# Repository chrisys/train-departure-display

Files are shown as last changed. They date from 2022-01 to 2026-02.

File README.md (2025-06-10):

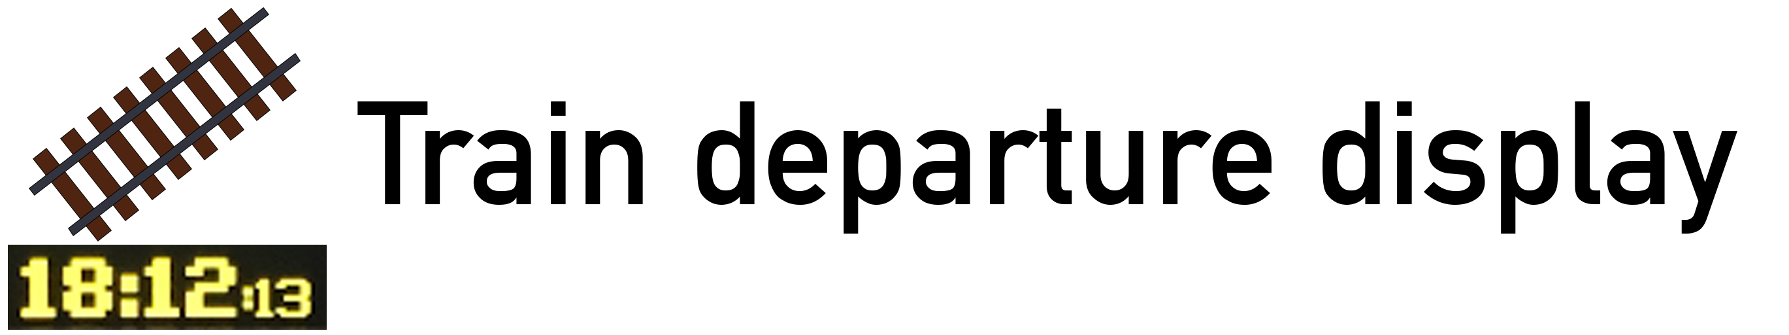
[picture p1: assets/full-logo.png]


**A replica, near real-time, miniature UK railway station train departure sign based upon a Raspberry Pi Zero and 256x64 SPI OLED display(s). Uses the publicly available [OpenLDBWS API by National Rail Enquiries](https://www.nationalrail.co.uk/).**

## Highlights

- **See local departures**: Display the depatures from your local station at home for up to date train information.
- **3D-printable cases**: Print your own miniature case to keep everything tidy - both desktop and 'hanging' style available.
- **Dual display support**: Run two displays each showing departures from different platforms from a single Raspberry Pi.

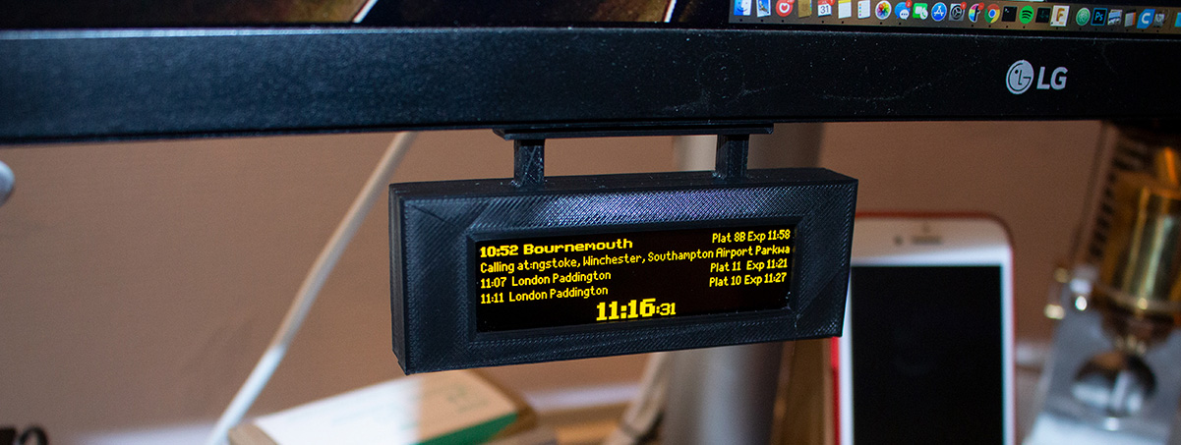
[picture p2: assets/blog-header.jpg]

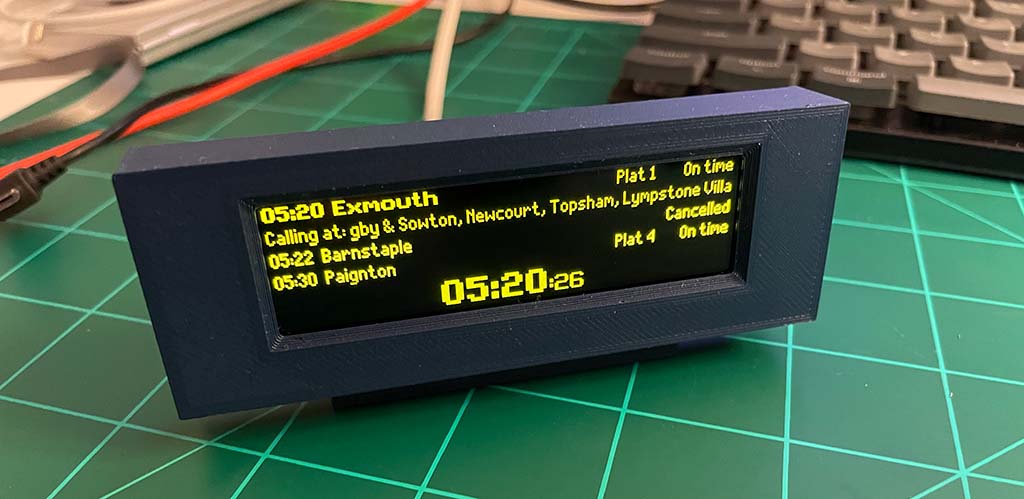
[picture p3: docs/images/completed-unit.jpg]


## How to build

**Check out [the documentation](/docs/01-getting-started.md) for full hardware/software requirements and complete build guide.**

- [Getting Started](/docs/01-getting-started.md)
- [Connecting the display to the Pi](/docs/02-connecting-the-display-to-the-pi.md)
- [Assembling the Case](/docs/03-assembling-the-case.md)
- [Configuration](/docs/04-configuration.md)

## Credits

A big thanks to [Chris Hutchinson](https://github.com/chrishutchinson/) who originally started this project and inspired me to develop it further. [Blake](https://github.com/ghostseven) made some further improvements and this project was forked from [there](https://github.com/ghostseven/UK-Train-Departure-Display).

The fonts used were painstakingly put together by `DanielHartUK` and can be found on GitHub at https://github.com/DanielHartUK/Dot-Matrix-Typeface - A huge thanks for making that resource available!

Thanks to [@jajasilver](https://github.com/jajsilver/UK-Train-Departure-Display-NRE) and [@MatthewAscough](https://github.com/MatthewAscough/UK-Train-Departure-Display-NRE) for forming the basis of the OpenLDBWS implementation.

Thanks to [@cr3ative](https://github.com/cr3ative) and [@CalamityJames](https://github.com/CalamityJames) for the huge performance improvements and clean up in v0.5.0.

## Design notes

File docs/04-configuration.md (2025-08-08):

# Configuration

Sign up for the [National Rail Enquiries OpenLDBWS API](http://realtime.nationalrail.co.uk/OpenLDBWSRegistration), which will generate an token for you to use as the API key.

Only the API key is required to make the project run, everything else is optional but of course it may make sense for you to at least choose your preferred your station.

These environment variables are specified using the [balenaCloud dashboard](https://www.balena.io/docs/learn/manage/serv-vars/), allowing you to set up mutiple signs in one fleet for different stations.

| Key | Example Value
|---|---
|`apiKey` **(REQUIRED)** | `xxxxxxxx-xxxx-xxxx-xxxx-xxxxxxxxxxxx` (OpenLDBWS API key)
|`TZ`  | `Europe/London`, will default to UTC if not set ([timezones](https://en.wikipedia.org/wiki/List_of_tz_database_time_zones))
|`departureStation`  | `PAD` ([station code](https://www.nationalrail.co.uk/stations_destinations/48541.aspx))
|`destinationStation`  | `HWV` ([station code](https://www.nationalrail.co.uk/stations_destinations/48541.aspx)) [optional] Filters trains shown to only those that call at this station
|`timeOffset`  | `5` [optional] (Time offset, in minutes, for the departure board. Can be used to see into the future (positive value) or past (negative value). Set 5 if you live 5 min from the station and want to hide departures that are too soon to catch)
|`refreshTime` | `120` (seconds between data refresh)
|`screenRotation` | `2` (rotates the output of the OLED, 0 for when using the desk stand, 2 for the monitor mount ([docs](https://luma-oled.readthedocs.io/en/latest/api-documentation.html#luma.oled.device.ssd1322)))
|`operatingHours` | `8-22` (hours during which the data will refresh at the interval above - leave blank to run all day)
|`screenBlankHours` | `1-6` (hours during which the screen will be blank and data will not refresh - leave blank to never blank)
| `outOfHoursName` | `London Paddington` (name shown when current time is outside the `operatingHours`)
| `dualScreen` | `True` (if you are using two displays)
| `screen1Platform` | `1` (sets the platform you want to have displayed on the first or single-screen display)
| `screen2Platform` | `2` (sets the platform you want to have displayed on the second display)
| `individualStationDepartureTime` | `False` (Displays the estimated or scheduled time of the service at each leg of a journey)
| `fpsTime` | `4` (adjusts how often the effective FPS is displayed)
| `headless` | `True` (outputs to noop serial device rather than serial port; useful for running on a development machine)
| `showDepartureNumbers` | `True` (adds 1st / 2nd / 3rd as per UK train departures)
| `firstDepartureBold` | `False` (makes the first departure use either the bold or normal font)
| `targetFPS` | `20` (Frame rate regulator FPS target; 0 disables the regulator, which will increase FPS on constrained CPU, but will run the CPU hot at 100%.)
| `debug` | `False` (Display debugging information; `True` shows the debug info permanently, any integer `>1` will show instead of the splash screen for that number of seconds)

If using two screens the following line needs to be added into /boot/config.txt which is achieved by using the 'Define DT overlays' option within the Device configuration screen on balenaCloud: `spi1-3cs`



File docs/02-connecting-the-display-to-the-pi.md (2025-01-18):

# Connecting the display to the Pi

The next thing we need to tackle once you have obtained what you need from the [hardware required](01-getting-started.md#hardware-required) list is connecting the display to the Raspberry Pi and assembling the case.

## Configuring the display

Some displays have a solder-blob or zero-ohm resistor jumper on the back of the board that you may need to move in order to enable the display for SPI communication. In the case of my display it meant moving `R6` to `R5` to enable 4SPI as dictated by a small data table printed on the back of the display board. This may not be necessary if you get a different display, but it has been for every display I have used so far.

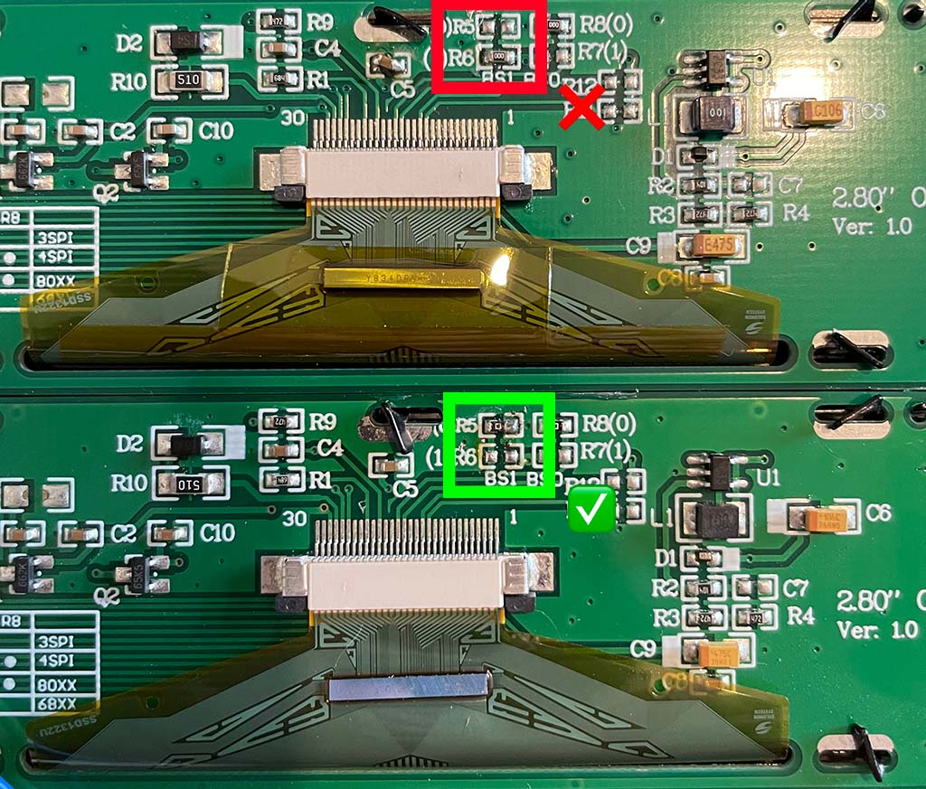
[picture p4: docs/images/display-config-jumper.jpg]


**Note:** this resistor is of zero value, so if it's easier you can remove it from one position and just bridge the pads with solder instead. A user also reported it's possible to do this with conductive paint in the case you are building the project without soldering.

## Required connections

The connections for one of these displays to the Raspberry Pi GPIO header are as follows, but **it would be a good idea to check the connections with the datasheet of your particular display before powering on** as there's no guarantee yours will match the pinout of mine.

### Display 1

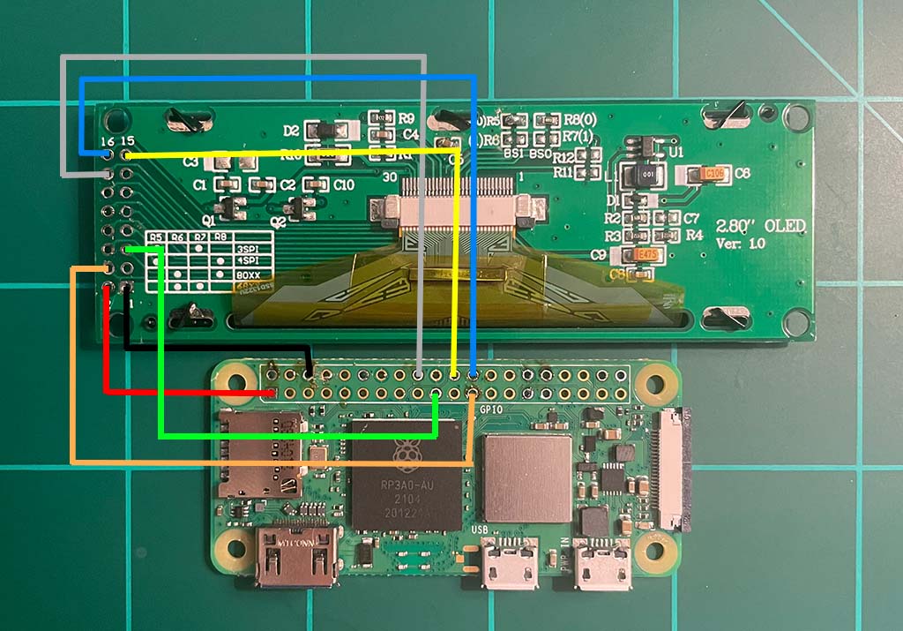
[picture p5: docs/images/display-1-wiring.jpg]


| Display | Connection | Raspberry Pi
|---|---|---
| 1 | Ground | 6 (Ground) |
| 2 | V+ (3.3V) | 1 (3v3 Power) |
| 4 | `D0/SCLK` | 23 (`BCM11 SCLK`) |
| 5 | `D1/SDIN` | 19 (`BCM10 MOSI`) |
| 14 | `DC` (data/command select) | 18 (`BCM24`) |
| 15 | `RST` (reset) | 22 (`BCM25`) |
| 16 | `CS` (chip select) | 24 (`BCM8 CE0`)

### Display 2 (optional)
**Note:** when using 2 displays there's [additional configuration required](./04-configuration.md).
| Display 2 | Connection | Raspberry Pi
|---|---|---
| 1 | Ground | 25 (Ground) |
| 2 | V+ (3.3V) | 17 (3v3 Power) |
| 4 | `D0/SCLK` | 40 (`BCM21 SCLK`) |
| 5 | `D1/SDIN` | 38 (`BCM20 MOSI`) |
| 14 | `DC` (data/command select) | 29 (`BCM5`) |
| 15 | `RST` (reset) | 31 (`BCM6`) |
| 16 | `CS` (chip select) | 12 (`BCM18 CE0`)

## Making the connections

The idea when making the connections between the display and the Raspberry Pi is to be as neat as possible and keep the wires only as long as necessary. Space within the case is limited and any extra wiring may make it difficult to fit all of the components in.

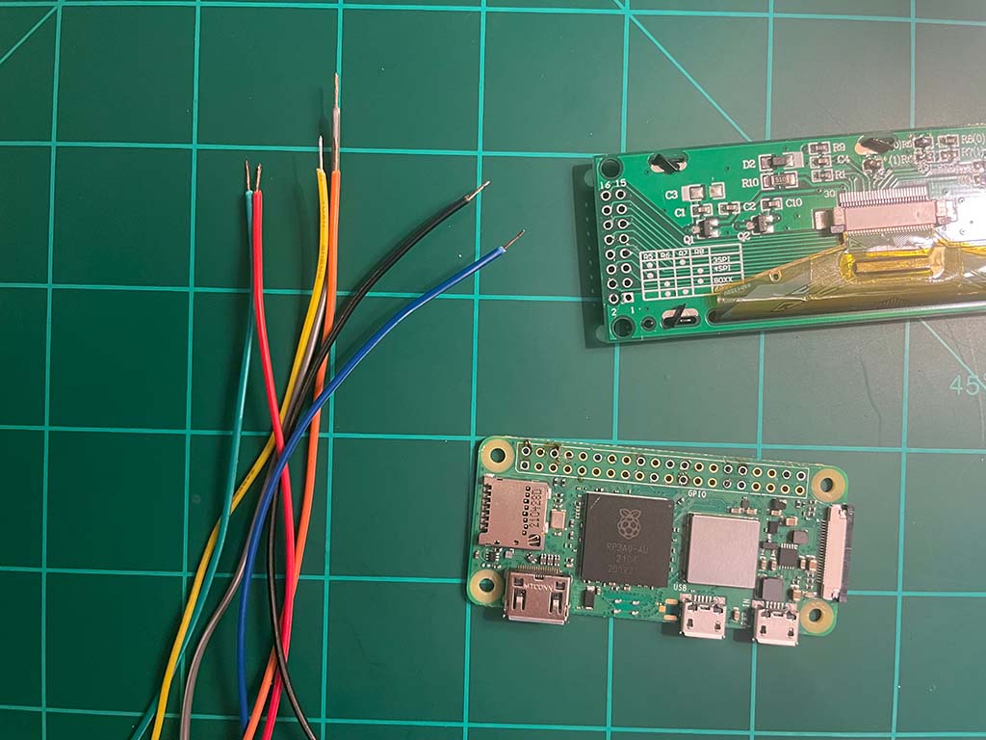
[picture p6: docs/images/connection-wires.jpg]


Strip the ends of each wire and make all the connections to the display first. I used the same colour wires as in my wiring diagram to save confusion.

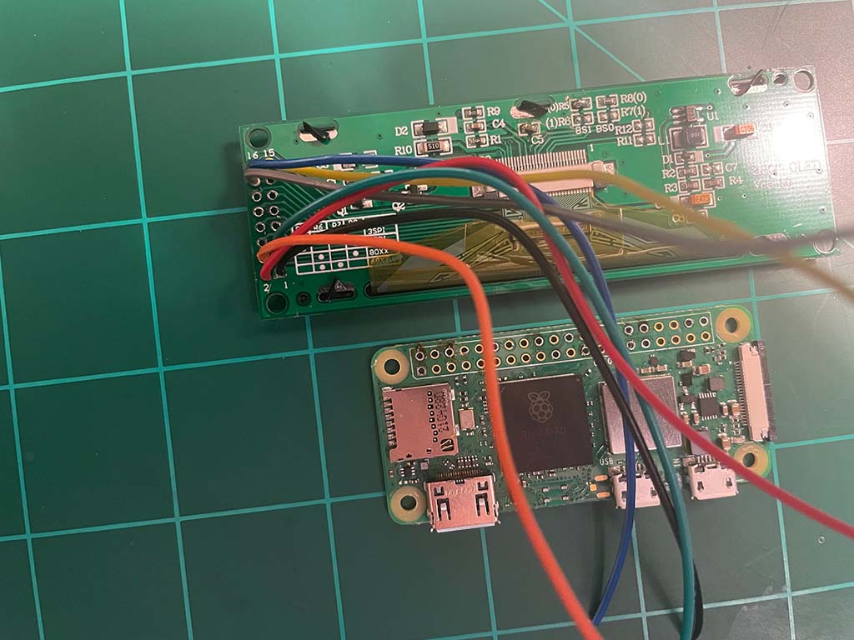
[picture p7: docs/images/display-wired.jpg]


Next, connect each of the wires to the appropriate place on the Pi, working from left to right. Again, make sure wires are only as long as necessary to make the connection.

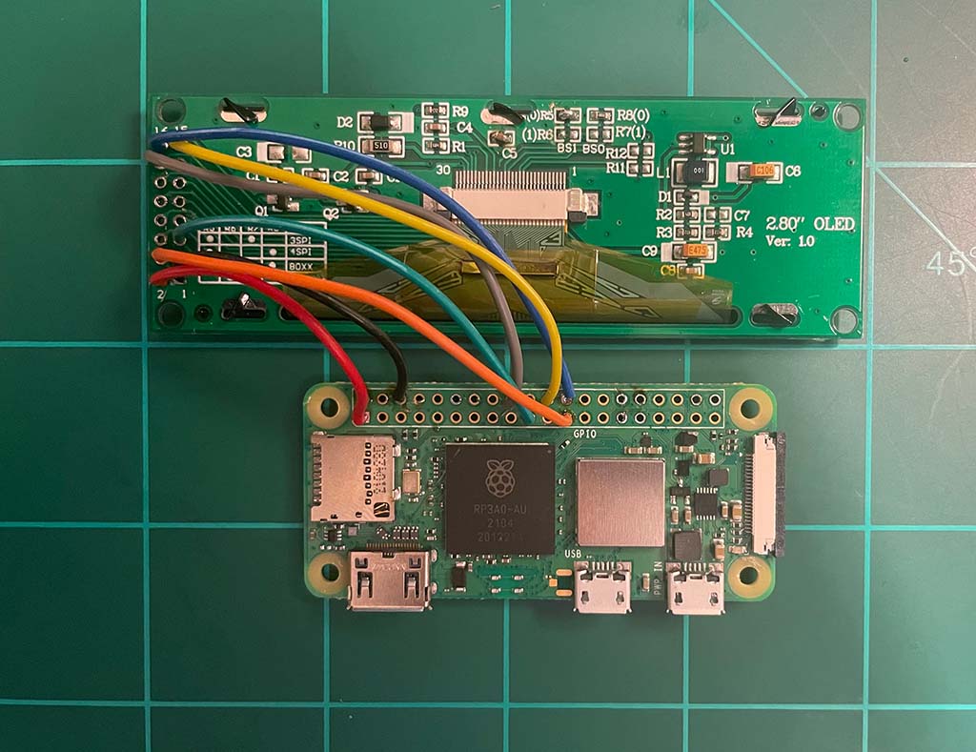
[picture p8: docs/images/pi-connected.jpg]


## Testing

At this point you can install the SD card into the Pi and power it up. If you've connected everything correctly you should see the initial welcome screen of the display, but nothing more since we haven't configured it yet (that comes later!).

## Troubleshooting

If at this point you're not seeing the Train Departure Display welcome screen, don't worry, just double check all of your connections one by one, and review the note at the beginning of this guide about the resistor/solder-blob configuration. It can be different per-display, and we need to make sure the display is set to 4-wire SPI mode before it will work.

**Next up: [Assembling the case](./03-assembling-the-case.md)**

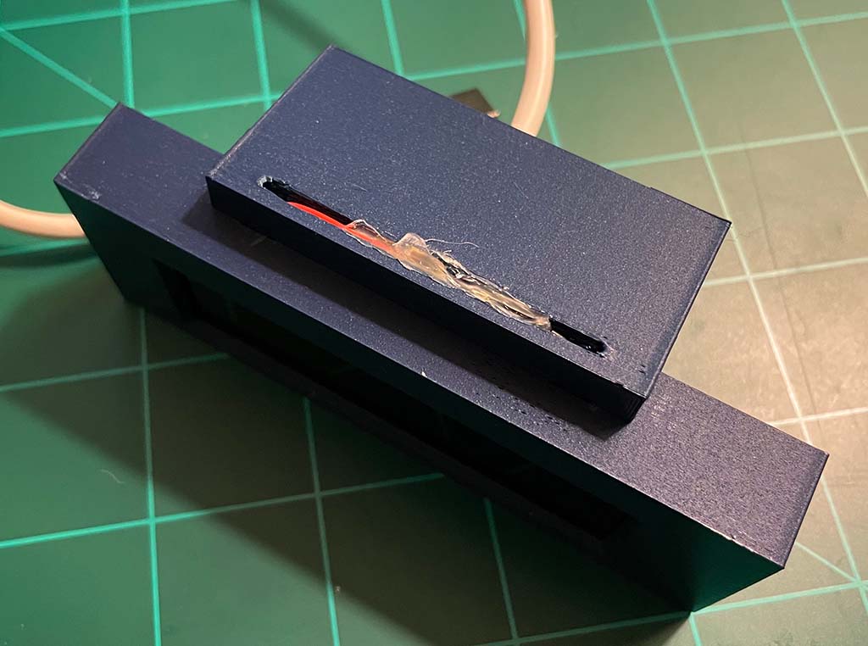
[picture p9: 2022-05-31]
docs/images/hot-glue.jpg

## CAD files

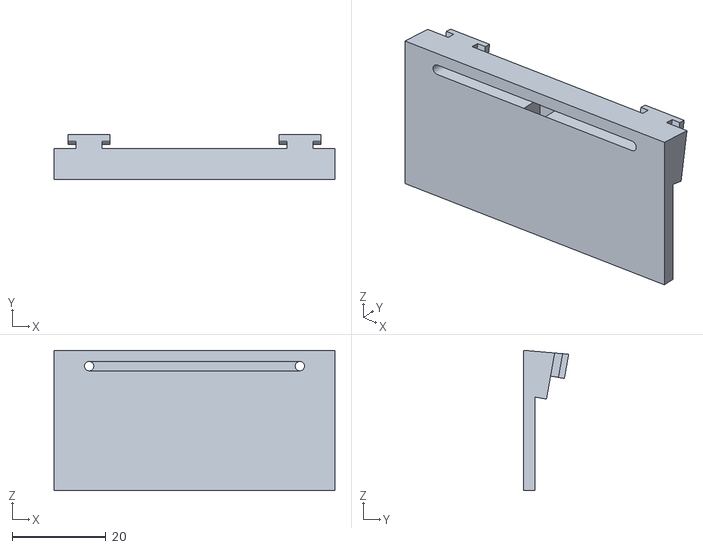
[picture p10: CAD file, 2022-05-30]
case/desk-mount.stl
60.0 x 9.70 x 30.0

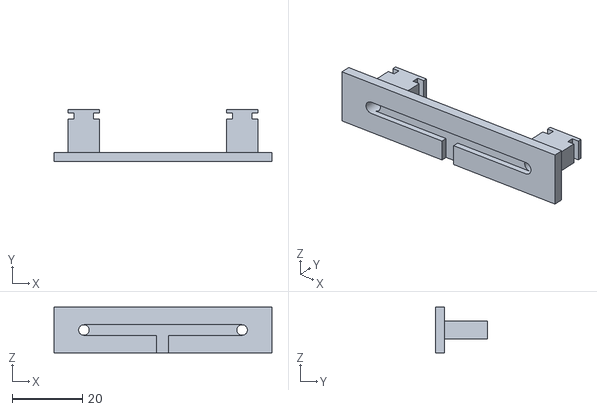
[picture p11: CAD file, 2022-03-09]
case/hanging-mount.stl
62.0 x 14.8 x 13.0

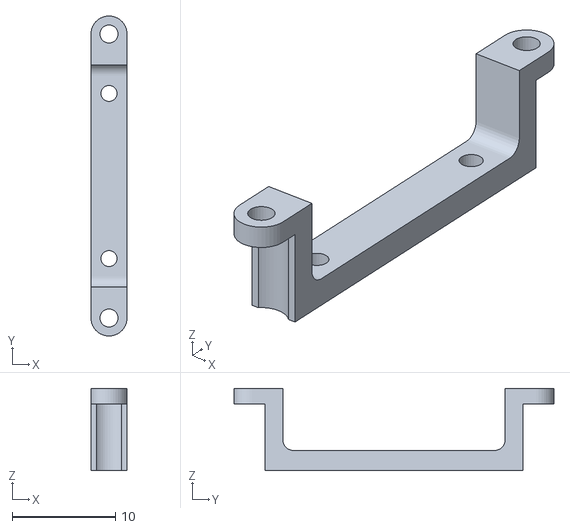
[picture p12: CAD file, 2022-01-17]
case/display-clamp.stl
3.50 x 31.0 x 7.95

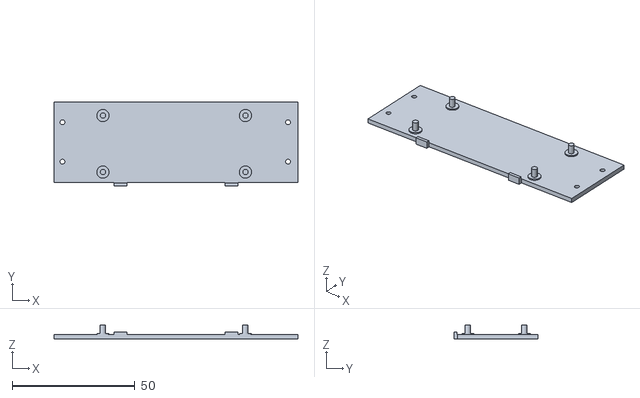
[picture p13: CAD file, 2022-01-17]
case/back-cover.stl
99.3 x 34.0 x 5.80

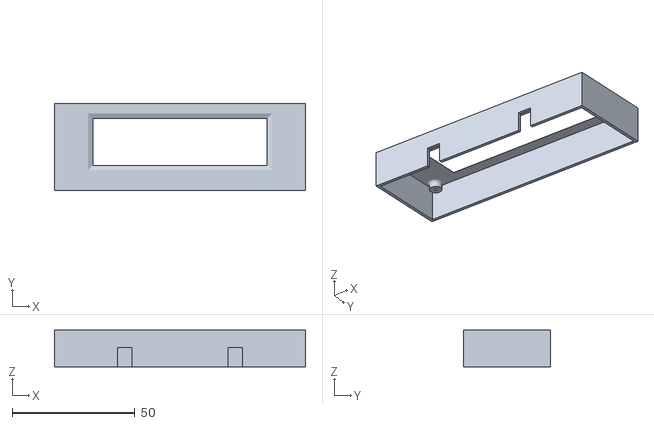
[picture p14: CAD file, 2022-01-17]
case/case-body.stl
102.2 x 35.5 x 15.0

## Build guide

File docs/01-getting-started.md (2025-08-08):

# Getting started

This project is designed to be easily reproducible by anyone with basic hardware assembly skills. Of course, you can reproduce the project exactly as designed, but you can also forego certain features in the interests of making it easier to assemble.

I have detailed the process of reproducing the project and building a unit exactly as I have done for myself, but you can definitely simplify the project if you don't want the same custom case.

**Soldering not required!** Although in the *ideal* setup, the connections between the display and the Raspberry Pi would be soldered in order to keep the profile of the two boards as low as possible without header pins, it is totally possible to make the connections using jumper-jerky/dupont wires and avoid the need to solder anything.

## Hardware required

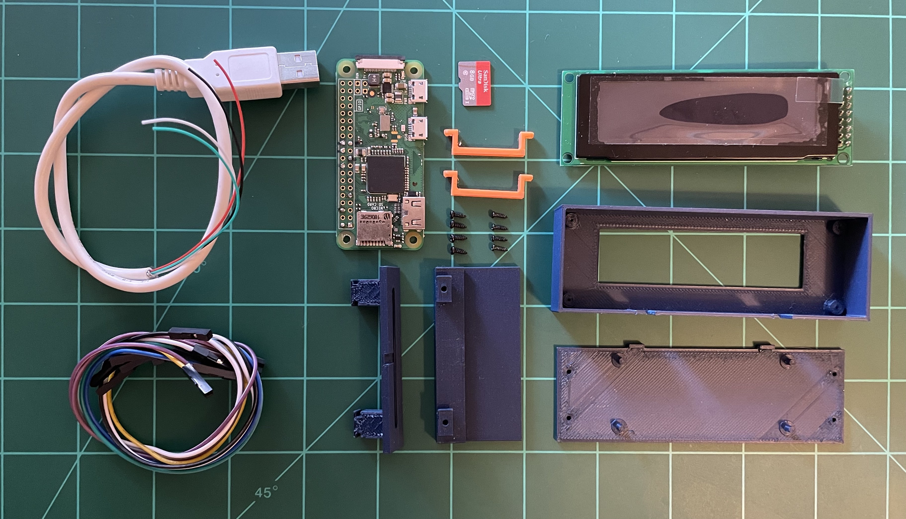
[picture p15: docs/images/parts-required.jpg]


   * 1x Raspberry Pi Zero 2 W (recommended) or Zero W
   * 1x Micro SD card (recommend Sandisk Ultra 8GB or larger)
   * 1x 2.8" SSD1322-based 256x64 SPI display (sample link below)
   * 1x 3D printed [case body](../case/case-body.stl)
   * 1x 3D printed [back cover](../case/back-cover.stl)
   * 2x 3D printed [display clamp](../case/display-clamp.stl)
   * 1x 3D printed [desk mount](../case/desk-mount.stl) *OR* [hanging mount](../case/hanging-mount.stl)
   * 4x M1.2x4mm self tapping screws to mount the display with the clamps
   * 4x M1.7x5mm self tapping screws to fit the back cover
   * 1x Power cable (e.g. a USB cable that can be cut)
   * Various small wires for connecting the Pi to the display; plain wires if you're soldering, otherwise jumper-jerky/dupont wires

For the screws, I usually purchase screw sets [like this from Amazon](https://www.amazon.co.uk/gp/product/B0915DPHV2) which last a while and provide for many different projects.

I have used [displays from AliExpress](https://www.aliexpress.com/item/33012440441.html)* successfully, but any other with the same pixel dimensions and controller chip should also work.
* This particular one comes with header pins pre-soldered, which may cause problems if you are using the 3D printed case.

This project is designed to run using a Raspberry Pi Zero W or Zero 2 W and therefore the case is designed to fit that device. If you intend to create your own case or not use a case, other Raspberry Pi devices will also work.

## Software required

- Software to flash an SD card ([balenaEtcher](https://balena.io/etcher))
- A free [balenaCloud](https://balena.io/cloud) account
- A free [National Rail Enquiries OpenLDBWS API](http://realtime.nationalrail.co.uk/OpenLDBWSRegistration) account
- (optional) A download of this project
- (optional) The [balena CLI tools](https://github.com/balena-io/balena-cli/blob/master/INSTALL.md)

This project has been built to be deployed using a free [balenaCloud](https://dashboard.balena-cloud.com) account. BalenaCloud allows you to deploy and update the project software in just a few clicks and takes all of the hassle out of installing and configuring software. 

## Installation

Once you have the free account set up, running this project is as simple as deploying it to a balenaCloud fleet. The basic premise is that you add a fleet, add your device (or devices - you can have more than one device running the same code!), and then deploy software. You can do it in just a few clicks by using the button below which will automatically guide you through adding your first fleet and deploying the code.

balena deploy button (https://dashboard.balena-cloud.com/deploy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)

Once your SD card has been flashed, set it aside as we'll need it later after we have assembled the hardware.

To update at a later date, simply return to this page and click the above button again to deploy the latest code to your existing fleet. Your device will automatically update over-the-air!

**Alternatively**, sign up, add a fleet and device as per the [getting started](https://www.balena.io/docs/learn/getting-started/raspberrypi3/python/) guide. Then use the [balena CLI](https://github.com/balena-io/balena-cli) to push the project to your Pi.

This allows you to easily deploy multiple devices and configure them from the dashboard with the following variables.

## Printing the case

For printing I recommend orientating the parts as below, noting that the hanging mount will require supports, although I also recommend blocking the supports from filling the holes - they can be tough to remove and should print OK without support.

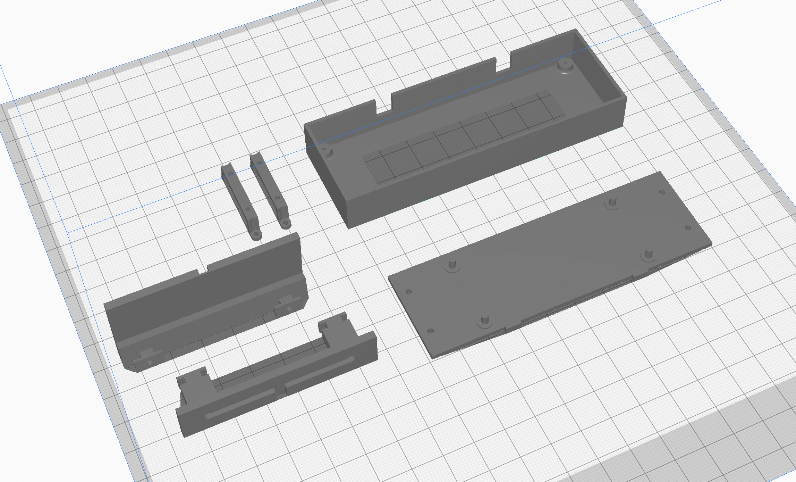
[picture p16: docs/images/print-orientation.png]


You should find that the case body prints slightly larger than necessary for the OLED to fit, the reason for this is to give you the freedom to center the display within the window on the front. I have found that the displays vary slightly when it comes to location of the display panel itself and sometimes are not centered.

**Next up: [Connecting the display to the Pi](./02-connecting-the-display-to-the-pi.md)**

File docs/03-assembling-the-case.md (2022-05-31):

# Assembling the case

Once you've [connected the display to the Pi](./02-connecting-the-display-to-the-pi.md) and confirmed it's working, and I do recommend doing that first, it's time to assemble everything in the case.

## Securing the display

The display is held into the case body using two display clamps. The display should be a somewhat loose fit into the case body to allow for you to center the display within the window given variances in displays that I've observed.

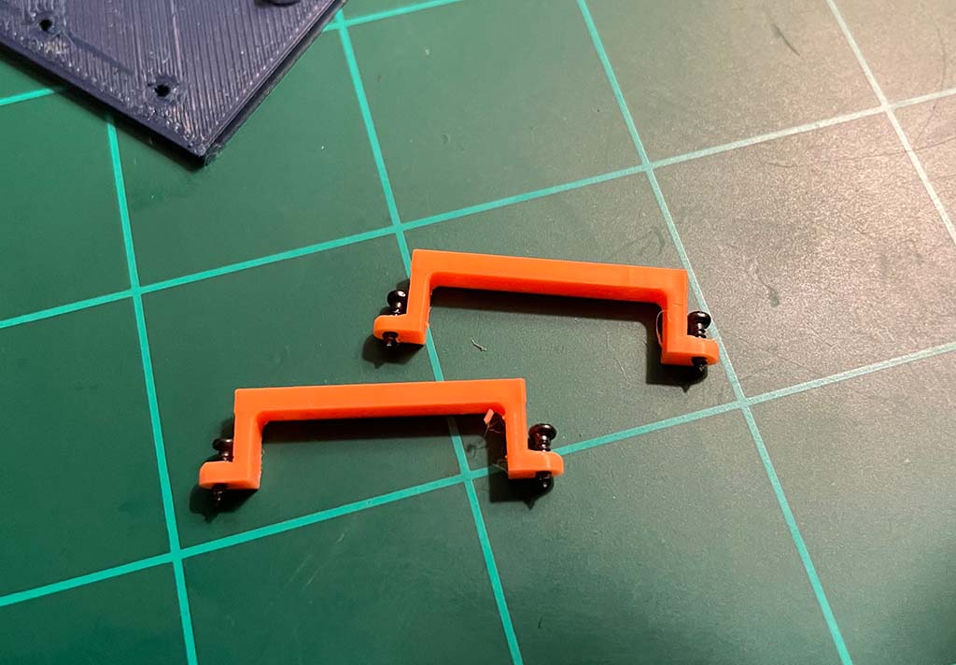
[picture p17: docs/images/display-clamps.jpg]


Use 4x M1.2x4mm self tapping screws (the smaller of the two sizes) to secure the clamps and the display. Gently tighten them as the screws are very small and prone to either stripping the threads or snapping.

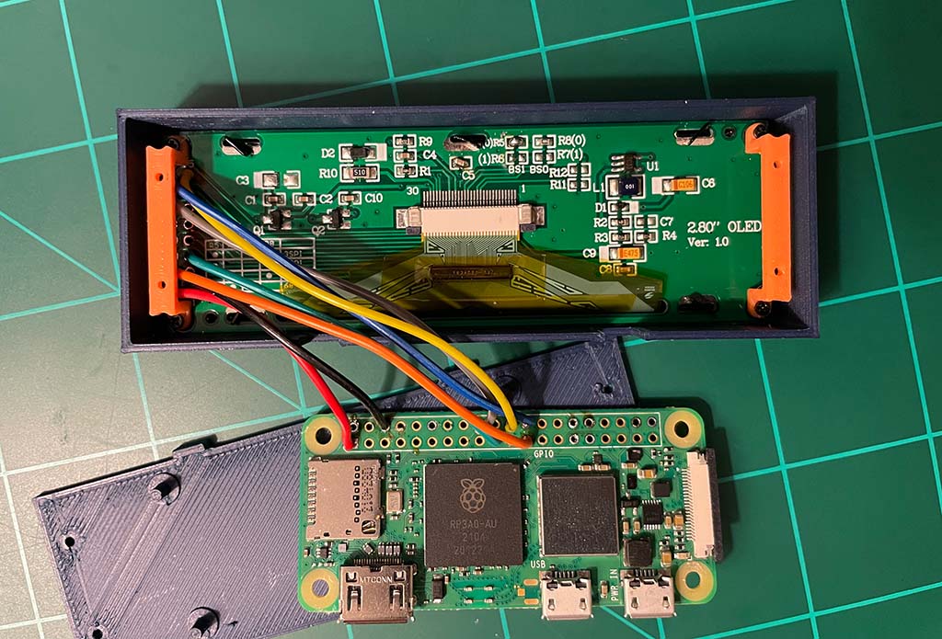
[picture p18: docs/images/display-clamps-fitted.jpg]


## Securing the Pi

Next, the Pi should be secured to the back cover. This is achieved by placing the Pi onto the 4 mounting posts and then melting the posts flat with a soldering iron. The 3D-printed plastic melts easily to fill the holes in the Pi PCB. The approach should be to flatten the posts out over the hole to provide a secure mounting.

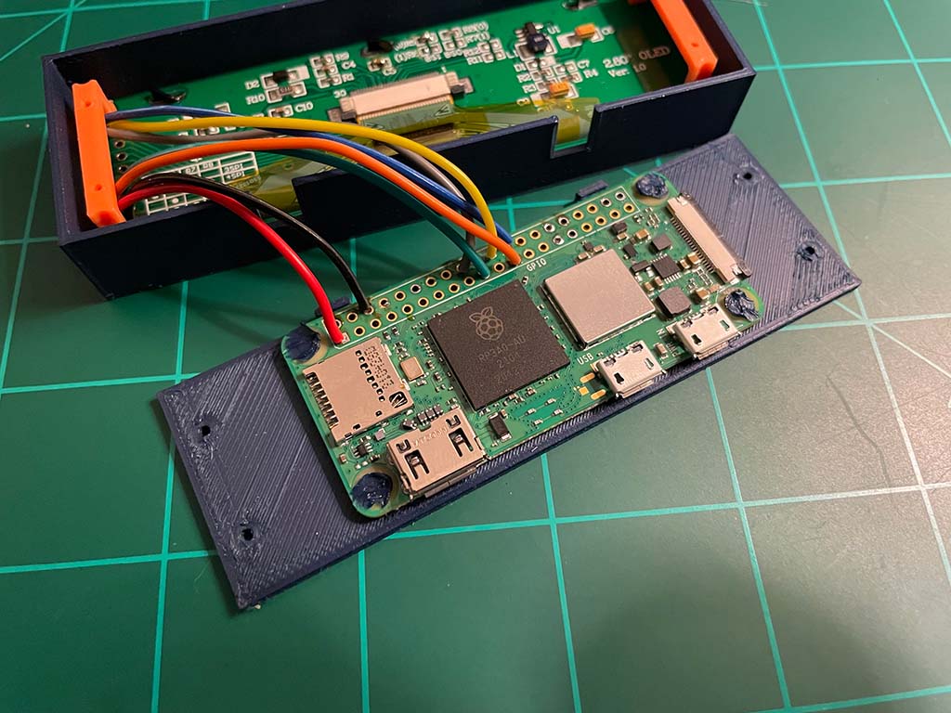
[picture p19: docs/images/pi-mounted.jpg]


Now's a good time to install your SD card again (if necessary) as it will become more difficult to do so as we continue with the assembly of the case.

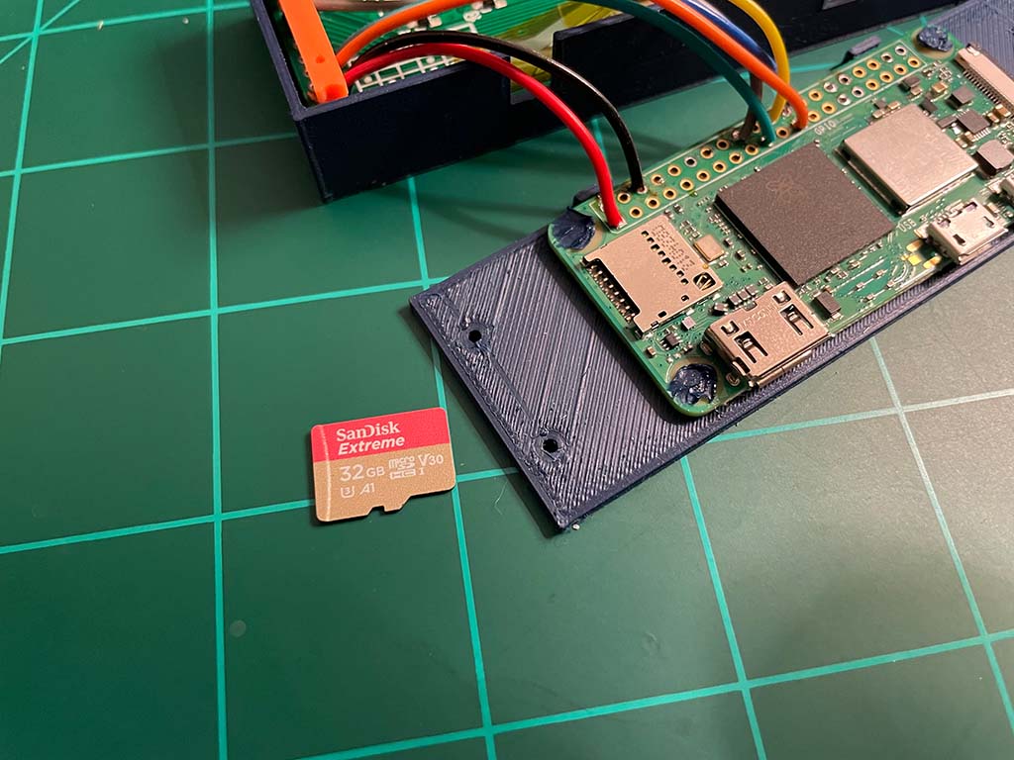
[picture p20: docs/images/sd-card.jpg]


## Power cable and mounting

Next, we need a method of powering the device. There are holes in both the desk mount and the hanging mount that allow you to pass through two wires, a positive and negative connection, in order to power the Pi and the display.

As noted in the parts list, I used a USB cable I could cut open for this purpose, but really you could use any 5V power supply as long as the wires are thin enough. If you cut open a cable be sure to test the wires using a multimeter to ensure that they are color coded as you expect. Don't rely on red and black to be positive and negative.

First route the wires through your chosen mounting, noting that the positive and negative need to be placed as pictured for the easiest and tidiest connection to the Pi.

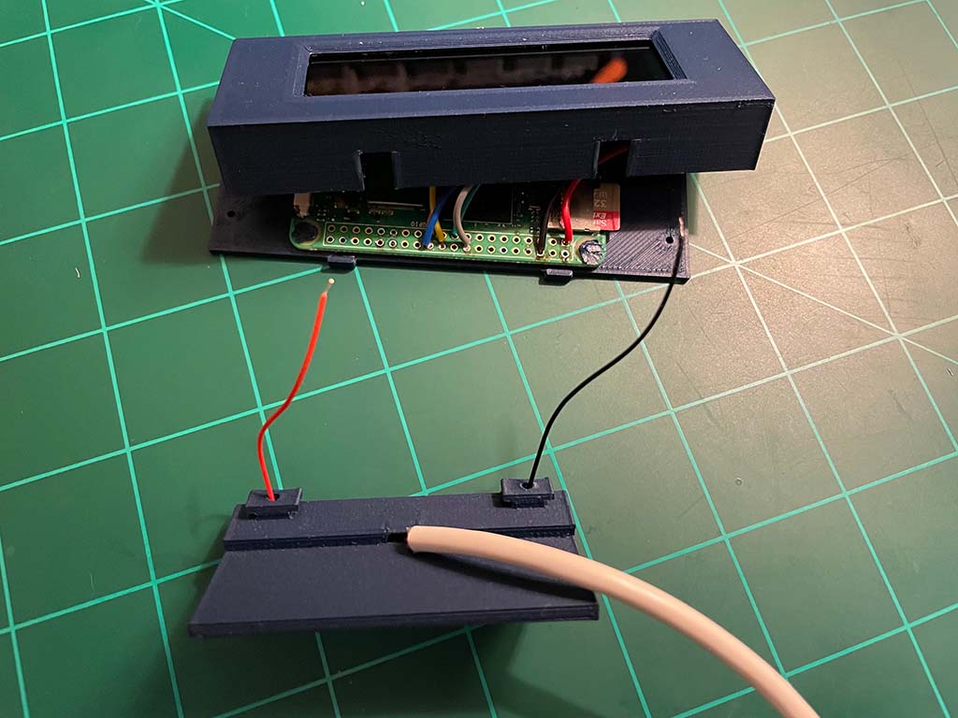
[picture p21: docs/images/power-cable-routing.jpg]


Next, position the case and Pi as pictured below, and solder the power wires to the Pi.

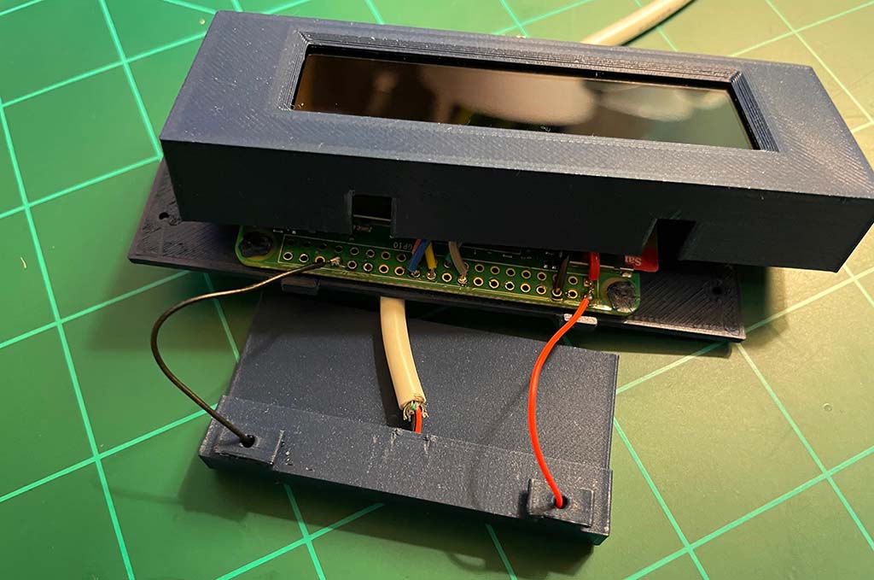
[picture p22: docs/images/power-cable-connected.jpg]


Connect the positive (+5V) wire to pin 2 on the Pi and connect the ground wire to any ground pin available (I used pin 34).

## Closing the case

Finally, the last part of the assembly is to install the back cover of the case using 4x M1.7x5mm self tapping screws.

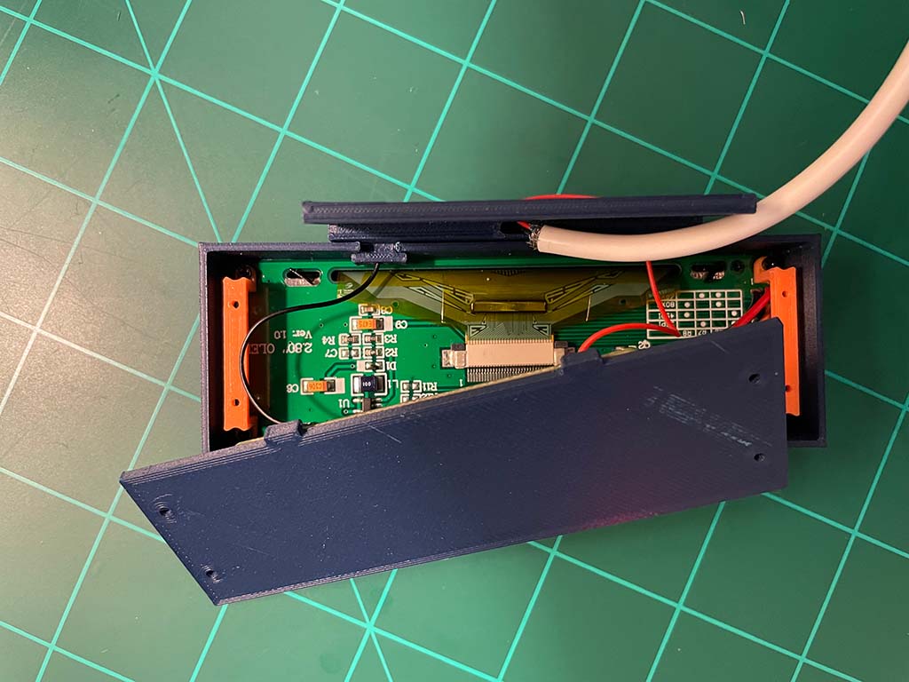
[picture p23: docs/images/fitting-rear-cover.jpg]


Ensure that all wires are neatly fitted within the case and do not cover the clamps in any way.

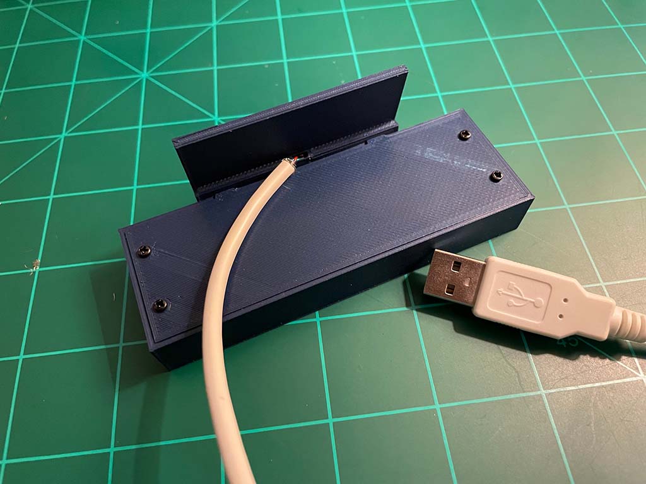
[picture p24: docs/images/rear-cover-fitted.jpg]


**Next up: [Configuration](./04-configuration.md)**

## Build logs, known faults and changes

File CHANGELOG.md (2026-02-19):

# Changelog

## [0.6.3](https://github.com/chrisys/train-departure-display/compare/v0.6.2...v0.6.3) (2026-02-19)

### Bug Fixes

* **dualscreen:** Independent scrolling of 'calling at' ([5075551](https://github.com/chrisys/train-departure-display/commit/50755515d432eb3405880d5d6d76b869b2c80ac4))
* Update requirements.txt to remove security issues ([06dd404](https://github.com/chrisys/train-departure-display/commit/06dd40471b25b7151f5d60652634bd504fae7686))

From this point onwards the project was moved to use Release Please and conventional commits. The change log below is retained for historical purposes.

---

## v0.6.2
## (2025-08-08)

* Resolve dependency issue with RPi.GPIO and spidev [Chris Crocker-White]

## v0.6.1
## (2025-08-08)

* Update documentation fixes #136 [steco]
* Suppress "GPIO in use" error fixes #111 [steco]

## v0.6.0
## (2025-06-19)

* Migrate away from deprecated balenalib base images (and also reduce image size) fixes #138 [Chris Crocker-White]
* Add extra character to platform placeholder text to prevent overlapping text fixes #123 [Chris Crocker-White]
* Convert boolean values read from env vars into uppercase before comparison fixes #106 [Chris Crocker-White]
* Add version and date to startup fixes #75 [Chris Crocker-White]
* Remove reference to kits from README.md closes #94 [Chris Crocker-White]

## v0.5.5
## (2024-02-27)

* Fix regex for platform numbers above 10 [CalamityJames]

## v0.5.4
## (2023-07-26)

* Add alternate validation, allowing use of non-numeric platforms [CalamityJames]

## v0.5.3
## (2023-07-26)

* Load 10 rows by default, to get the most from the API call [CalamityJames]

## v0.5.2
## (2023-07-22)

* New feature: Debug screen support [CalamityJames]

## v0.5.1
## (2023-07-04)

* Readded `tzdata` to set timezone, fixes #36 again, sorry! [CalamityJames]

## v0.5.0
## (2023-06-29)

* Upgrade: Switch Python version and base OS: Python 3.11 on Alpine
* New feature: `showDepartureNumbers` option - Adds 1st / 2nd / 3rd prefix as per UK train departures
* New feature: `firstDepartureBold` option - toggle bold of first departure line as this is regional
* New feature: `targetFPS` option - configurable FPS regulator (zero to disable)
* Development UX: `fpsTime` option - Adjusts how frequently the Effecive FPS is displayed
* Development UX: `headless` option - Run using emulated serial port (Useful for optimisation checks)
* Development UX: Skip NRE attribution sleep in emulation mode
* Development UX: Simplify Dockerfile slightly in an attempt to be Balena-y
* Performance: Seconds now render every 0.1 second, rather than a hotspot (reduce CPU)
* Performance: All "in-loop" TTF font rendering is now cached (reduce CPU)
* Fix: screen1Platform/screen2Platform being required incorrectly on the env

## v0.4.0
## (2023-02-18)

* Fix: Catches request errors to draw blank signage [BeauAgst]
* New feature: Add individualStationDepartureTime option [BeauAgst]
* Fix: Correct some boolean config vars defaulting to true [Chris Crocker-White]

## v0.3.8
## (2023-01-26)

* Correctly handle when platform numbers set to null [Chris Crocker-White]

## v0.3.7
## (2023-01-20)

* Correct crash when destinationStation set to null [Chris Crocker-White]

## v0.3.6
## (2023-01-13)

* Remove usage of deprecated Pillow method [Chris Crocker-White]

## v0.3.5
## (2023-01-13)

* Update balena.yml template variables [Chris Crocker-White]

## v0.3.4
## (2022-05-31)

* Add assembly guide [Chris Crocker-White]

## v0.3.3
## (2022-05-30)

* Correct angle on desk mount lugs [Chris Crocker-White]

## v0.3.2
## (2022-05-16)

* Default to all-day operation fixes #72 [Chris Crocker-White]

## v0.3.1
## (2022-03-08)

* Adjust tolerances between case parts [Chris Crocker-White]

## v0.3.0
## (2021-12-09)

* Add modular case design [Chris Crocker-White]

## v0.2.0
## (2021-12-09)

* Enable dual display output [Lee Porte]

## v0.1.3
## (2021-12-09)

* Set Dockerfile to use raspberry-pi base image [Chris Crocker-White]

## v0.1.2
## (2021-12-08)

* Update timeOffset key [Lee Porte]

## v0.1.1
## (2021-10-29)

* Add screenBlankHours [Chris Crocker-White]

## v0.1.0
## (2021-10-29)

* Change to National Rail Enquiries API [Chris Crocker-White]

## v0.0.15
## (2021-08-02)

* Add `tzdata` to set timezone, fixes #36 [Chris Crocker-White]

## v0.0.14
## (2021-07-29)

* Reduce container size (~315MB to ~87MB) [Chris Crocker-White]

## v0.0.13
## (2021-07-12)

* Relocate update data log [Chris Crocker-White]

## v0.0.12
## (2021-07-12)

* Add logging, adjust framerate [Chris Crocker-White]

## v0.0.11
## (2021-07-09)

* Fix outOfHoursName config [Chris Crocker-White]

## v0.0.10
## (2021-07-08)

* Report API server errors fixes #29, fixes #32 [Chris Crocker-White]
* Reworked messy configuration setup [Chris Crocker-White]
* Added ability to filter by platform closes #7 [Chris Crocker-White]
* Reduce container size (~780MB to ~300MB) [Chris Crocker-White]

## v0.0.9
## (2021-05-20)

* Mark fleet as not joinable [Chris Crocker-White]

## v0.0.8
## (2021-04-01)

* docs: add query params to deploy link [Aaron Shaw]

## v0.0.7
## (2021-02-01)

* Update balena.yml [Chris Crocker-White]

## v0.0.6
## (2021-01-01)

* Add balena.yml and logo for hub [Chris Crocker-White]

## v0.0.5
## (2020-09-08)

* Add balena.yml with device and env var presets [Chris Crocker-White]

## v0.0.4
## (2020-09-08)

* Add DWB button for easier deployment [Chris Crocker-White]

## v0.0.3
## (2020-05-26)

* Unlock framerate [Chris Crocker-White]

## v0.0.2
## (2020-05-26)

* Add repo.yml [Chris Crocker-White]
* Improve local development [Chris Crocker-White]
* Remove piwheels - not currently building [Chris Crocker-White]
* Update readme to include destinationStation option [Chris Crocker-White]
* Added datasheet for similar display [Chris Crocker-White]
* Added connection diagram [Chris Crocker-White]
* Added 3D case STL files [Chris Crocker-White]
* Added +x to balena-run fixes #2 [Chris Crocker-White]
* Rotate display [Chris Crocker-White]
* Reduce image size further and reduce framerate to improve performance on Pi Zero [Chris Crocker-White]
* Update README with balena and hardware setup [Chris Crocker-White]
* Removed unused packages and simplified to reduce image size [Chris Crocker-White]
* Tidying plus bug fixes to handle empty values from the API [Chris Crocker-White]
* Handle data with no platform info [Chris Crocker-White]
* Visual formatting changes, addition of platform [Chris Crocker-White]
* Change layout to prevent font stretching and add line [Chris Crocker-White]
* Add Dockerfile and README for balenaCloud use [Chris Crocker-White]

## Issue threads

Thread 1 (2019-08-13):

SPI Device Not Found

Kincade120, 2019-08-13:
Attempting to run the python code on Raspian, I get

```
/home/pi/.local/lib/python3.7/site-packages/luma/core/interface/serial.py:185: RuntimeWarning: This channel is already in use, continuing anyway.  Use GPIO.setwarnings(False) to disable warnings.
  self._gpio.setup(pin, self._gpio.OUT)
Traceback (most recent call last):
  File "/home/pi/.local/lib/python3.7/site-packages/luma/core/interface/serial.py", line 280, in __init__
    self._spi.open(port, device)
FileNotFoundError: [Errno 2] No such file or directory

During handling of the above exception, another exception occurred:

Traceback (most recent call last):
  File "./src/main.py", line 256, in <module>
    serial = spi()
  File "/home/pi/.local/lib/python3.7/site-packages/luma/core/interface/serial.py", line 284, in __init__
    raise luma.core.error.DeviceNotFoundError('SPI device not found')
luma.core.error.DeviceNotFoundError: SPI device not found
```

My python version is 3.7.3

 Not sure where Im going wrong here.

stuartbain, 2019-08-14:
Is SPI enabled in Raspbian?

`sudo raspi-config`

Select 5 Interfacing Options, then P4 SPI, Yes (to enable the SPI interface)

KeirDavis1, 2019-08-18:
@stuartbain That fixed it for me! Thankyou!

chrisys, 2019-08-19:
Good stuff @KeirDavis1 - thanks for helping @stuartbain. Would be great to see some photos when you finish the project.

KGS-STEAM, 2023-02-09:
Hi, I'm getting a similar error trying to run through the balena deployment, any help appreciated. I can see that the "spi=on" DT parameter is set so not sure what's going on.

Starting Train Departure Display v0.3.8
 main  /usr/src/python-packages/luma/core/interface/serial.py:206: RuntimeWarning: This channel is already in use, continuing anyway.  Use GPIO.setwarnings(False) to disable warnings.
 main    self._gpio.setup(pin, self._gpio.OUT)
 main  Traceback (most recent call last):
 main    File "/usr/src/python-packages/luma/core/interface/serial.py", line 309, in __init__
 main      self._spi.open(port, device)
 main  FileNotFoundError: [Errno 2] No such file or directory
 main
 main  During handling of the above exception, another exception occurred:
 main
 main  Traceback (most recent call last):
 main    File "src/main.py", line 325, in <module>
 main      serial1 = spi(port=1,gpio_DC=5, gpio_RST=6)
 main    File "/usr/src/python-packages/luma/core/interface/serial.py", line 320, in __init__
 main      raise luma.core.error.DeviceNotFoundError('SPI device not found')
 main  luma.core.error.DeviceNotFoundError: SPI device not found

BobBurrows48, 2023-02-10:
Having exactly the same issues as KGS-STEAM. tried on both a pi zero w and a pi zero 2 w. same outcome. Was worried I'd brought a duff screen but maybe not.

any help would obviously be really appreciated.

many thanks

Bob

gjwell, 2023-02-11:
Same here, I have tried 2 Pi zero w's two different displays. I have changed the 0Ohm resistor from R6 to R5 to enable 4SPI. triple checked wiring. metered out connections to ensure continuity and checked 3v supply to display. I guess the next thing to try is check the displays with an arduino.

any help would  be really appreciated.

Dreadmond, 2023-02-11:
Have you tried adding spi1-3cs using the “Define DT overlays” option? It’s
found under device configuration on balena cloud.

It’s mentioned in the guide for setting up dual screens, but I seemed to
need it for a single screen.

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

gjwell, 2023-02-11:
@Dreadmond. You are a star!!  This is exactly what I needed. Just tried it ant it works! Thank you so much for taking the time.

KGS-STEAM, 2023-02-11:
Agreed thank you so much @Dreadmond ! Worked like a charm!

chrisys, 2023-02-15:
Thanks for sharing this guys - I'll take a look here as this definitely wasn't necessary in the past!

chrisys, 2023-02-15:
Note to myself - it looks (from the logs) like the device is trying to run in dualScreen mode anyway, which explains why enabling the second SPI port resolves the error. Probably something to do with the recent changes to configuration options

jruys, 2023-02-17:
+1 - That setting fixed it for me too, thanks @Dreadmond! Already bough a replacement screen as I assumed the old one was broken.

chrisys, 2023-02-18:
OK should be fixed now - thanks for reporting it all!

Closed 2023-02-18.

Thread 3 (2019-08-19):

use National rail api

joural, 2019-08-19:
I found out that transport api is very unreliable, any chance of swapping to national rail api?

chrisys, 2019-08-20:
Hey @joural what problems did you have with it? I've been using Transport API for a few weeks and never had an issue - maybe we can contact them?

But otherwise I've no objections to adding the National Rail API as an option for people, it's good to have more options, right? 👍

joural, 2019-08-20:
The information from transport API doesn't seem to be as accurate as from national rail, national rail gets information directly from all TOCs. Like yesterday my screen was showing service as running late, when in reality it was starting late at start station, and was not longer calling at my stop=was cancelled, transport API didn't pick this up, same when there was distribution on my line, it was showing services that were meant to leave hour ago, as running on time...

joural, 2019-08-20:
I'm trying to change your code to take national rail, but is proving very difficult for my novice skills.
One thing to note is national rail API requires to display disclaimer message periodically and uses soap

madwort, 2019-08-23:
Hi @joural,

Sorry to hear you've seen some poor data quality on TransportAPI. We get our train data from amalgamating several different open data feeds direct from Network Rail, which allows us to make the data available for your use with no restrictions (disclaimer messages, rules on what the data can be used for, etc), and in a hopefully very convenient form (JSON API, rather than SOAP). We do sometimes diverge slightly from the National Rail Enquiries feed (for instance, the TOCs like to make assumptions about how much time late trains will make up between stops - which is not open data - so we give slightly different results in that case), but we're always trying to improve our data quality.

If you see specific instances where we're diverging significantly, please email us at support@transportapi.com with endpoint URL, observed API output & expected API output, and we'll try to look into what's happening. It's not always possible to look back in time with live train data, but it can tell us where to look to make improvements in future.

Thanks!
Tom Ward, TransportAPI

joural, 2019-08-23:
@madwort I appreciate the quality of data supplied by transport API, without being connected to the source (national rail), I can only imagine the lenghts to gather all that information. I will keep my eyes peeled and report 😉

madwort, 2019-09-13:
Hi @jajsilver ,
Yes, I can see that would be useful, I'll discuss with colleagues & file a feature request.
Bear in mind that if you're setting up a customised departure board for your own use, you can filter the live departures like this:
https://transportapi.com/v3/uk/train/station/STP/live.json?destination=SUO&calling_at=WIM
(shows only Sutton via Wimbledon trains)
Or alternatively, I think you can do further requests to TransportAPI's `/train/service` endpoint with the `train_uid`s from the live departure board to check their routes (but obviously that's going to generate a lot more requests...!)

jajsilver, 2019-10-06:
@joural @chrisys I set myself this as a project and have now had a go at rewriting to use National Rail OpenLDBWS (Darwin feed) in an attempt to teach myself Python! See my fork here:
https://github.com/jajsilver/UK-Train-Departure-Display-NRE
It now accommodates multiple destinations (trains that split) and the via attribute.
If you get the chance to test it out and let me know how it goes for you I'd be very grateful.

chrisys, 2019-10-08:
@jajsilver awesome, great work! I will give it a go sometime this week hopefully.

joural, 2019-10-08:
@jajsilver truly awesome, I will as well give it a go when I ll have spare time, thank you it truly is appreciated

Closed 2019-10-08.

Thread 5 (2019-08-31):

Add instructions how to power Pi Zero from GPIO ports

tomers, 2019-08-31:
It would be nice to add information how to power the Pi Zero. The original article at https://www.balena.io/blog/build-a-raspberry-pi-powered-train-station-oled-sign-for-your-desk/ describes how to use a USB cable for powering the zero, but it overlooks the information as how to connect the power and ground pins to the Zero board. I found it here: https://thepihut.com/blogs/raspberry-pi-tutorials/how-do-i-power-my-raspberry-pi

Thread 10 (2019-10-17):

How to change display size?

Domocn, 2019-10-17:
I would like to create my own train departure board using three 32 x 64 rgb led panels but i have no idea how to change the coding and i did not want to spend a fortune on the pre built ones as making it myself would be much more rewarding and cheaper!

chrisys, 2021-07-13:
@Domocn it's not going to be trivial to change the display size, but it wouldn't be too much work either. I would recommend taking a look at the Luma library which the project uses to interface with the display; it does have options for interfacing with other display types.

Changing the size would be a matter of reconfiguring the drawing routines to place the components of the display differently. The `drawSignage` method is the best place to start. You can see it's based on rows, so a simple start might be to remove some of the extra rows to reduce the height of the display.

Closed 2021-07-13.

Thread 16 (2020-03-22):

Sluggish scrolling/dropping seconds on clock

mehstg, 2020-03-22:
I have recently installed this, however I have noticed the clock does not smoothly "tick" sometimes dropping seconds. Is this a known issue? It seems everything is done in a single thread in the while True loop, wonder if this is causing the slow performance.

chrisys, 2020-04-09:
@mehstg I see the same thing on mine, this is related to #13 - definitely improvements could be made here!

Closed 2021-07-13.

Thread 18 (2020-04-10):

`config.json` not pushed because it is listed in `.gitignore`

pdcastro, 2020-04-10:
There is logic in the [balena-run.sh](https://github.com/balenalabs/uk-train-departure-display/blob/master/balena-run.sh) file to decide whether to use an existing `config.json` file or copy from `config.sample.json`.
```sh
if [ ! -f config.json ]; then
  cp config.sample.json config.json
  ...
```
Having seen that logic, I [advised a user in a forum thread](https://forums.balena.io/t/local-mode-not-working/92301/25) to create a `config.json` as I thought it would be more convenient than setting the environment variables on the command line when pushing to a local-mode device:
`balena push <ipAddress> --env var1=value1 --env var2=value2 ...`

They tried it and it failed. On investigation, I found that there was a line for `config.json` in the repo's `.gitignore` file. The CLI (`balena push`) currently considers both the `.gitignore` and `.dockerignore` files to decide what files to ignore (balena-io/balena-cli/issues/1032) when pushing to the cloud or to local devices, so the `config.json` file was not being pushed. Deleting the line for `config.json` in the `.gitignore` file solved the issue.

(If it is a design decision that `config.json` should not be pushed, then what would the use case be for the test in `balena-run.sh`?)

pdcastro, 2020-04-11:
The project's `config.json` file contains an API key (`transportApi.apiKey`) and it is not good practice to commit keys to git repositories, especially of course public ones. But removing the `config.json` line from the `.gitignore` file does require committing `config.json` to the repo: one could live with `git status` reporting "untracked files" for some time. Progress is being made on CLI issue balena-io/balena-cli/issues/1032, which will result in the CLI no longer considering the `.gitignore` file for what to push (looking at the `.dockerignore` file only). Once this CLI issue is resolved, the `config.json` line could be re-added to the `.gitignore` file.

chrisys, 2020-04-11:
@pdcastro you got it, the `config.json` was added to `.gitignore` for the reason of not committing these private keys. I've always worked with setting the variables on the command line when developing in local mode for this project.

pdcastro, 2020-04-11:
> I've always worked with setting the variables on the command line when developing in local mode for this project.

Thanks @chrisys. I gather that using a `config.json` file would similarly not work when pushing to the cloud, whether `git push` or `balena push`. So basically, at the moment (with `config.json` listed in the `.gitignore` file), it is not possible to use a `config.json` file with this project, whichever the push method or target.

The logic in the `balena-run.sh` script is that, if a `config.json` exists (currently "impossible"), it is used as is. If it doesn't exist, a `config.json` file is generated with the values from environment variables (whether the variables are set on the command line, or via the web dashboard). `balena-run.sh` runs on the device, not the development machine, so an auto-generated `config.json` file will exist on the device, not on the development machine.

I think it makes sense to remove `config.json` from `.gitignore`, which is not the same as requiring or recommending that users commit the file to some git repo (`balena push` does not require it). It is not even necessary to document the possibility of writing a `config.json` file. I am not proposing any changes to the Readme / documentation.

Then again, another option is to do nothing (in relation to this issue) and wait for CLI issue balena-io/balena-cli/issues/1032 to be resolved, at which point `balena push` will allow `config.json` to be pushed even if it is listed in the `.gitignore` file.

Closed 2020-05-26.

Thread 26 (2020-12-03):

Tweak to add London Underground stations

scotta228, 2020-12-03:
Would it be possible to add option via new variable and amendment in trains.py to allow the alternative web call?
London underground data calls require the Line name to be included in the call.

New variable: SERVICE_TYPE - value is text:    null / blank / train / tube        (I haven't looked at other networks)
New variable: SUB-TYPE - value is text: null / blank or text string [A-Z|a-z]*

URL - with null/blank entry in SERVICE_TYPE (presently in trains.py at line 22):
URL = f"http://transportapi.com/v3/uk/train/station/{departureStation}/live.json"

Non-null:
URL = f"http://transportapi.com/v3/uk/(service_type)/(sub_type)/(departureStation)/live.json"

e.g.
url = f"http://transportapi.com/v3/uk/tube/metropolitan/CLF/live.json"
url = f"http://transportapi.com/v3/uk/train/station/CFO/live.json"

of course these could be extended with another optional variable: PLATFORM - value null/blank or integer

if null / blank - url as above
not null/blank

URL = f"http://transportapi.com/v3/uk/(servicetype)/(line)/(departureStation)/(platform)/live.json"

Summary of suggested variables:

SERVICE_TYPE   "train" for Netwok Rail or "tube" for London Underground
SUB_TYPE          "station" for Network Rail or (underground line name) for London Underground
departureStation - no change
PLATFORM       (optional)

chrisys, 2021-01-18:
@scotta228 I'd love to see this implemented, it'd be great to get this into the project as an option.

scotta228, 2021-01-18:
Actually, there is a different project on GitHub using the TfL OpenAPI which better suits the tube. TfL data is based on arrivals, rather than departures, and there are problems at the end of lines (where the route starts), so it's far from perfect. I've tweaked this other project to work with the Balena architecture, but it needs to remain a completely separate project, as it uses a different data source with a completely different data hierarchy.

chrisys, 2021-01-19:
@scotta228 what project is that?

scotta228, 2021-01-19:
https://github.com/petykowski/London-TFL-Arrivals-Board

Closed 2021-01-18.

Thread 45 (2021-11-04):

Refresh screen occasionally shows welcome screen instead of blank screen.

mattanorak, 2021-11-04:
Occasionally, on refresh, I see the "Powered by National Rail Enquiries" message, then a blank screen, then the display resumes.  Here's an export from the log at the time that it happened:

```
03.11.21 22:27:18 (+0000)  main  Traceback (most recent call last):
03.11.21 22:27:18 (+0000)  main    File "src/main.py", line 336, in <module>
03.11.21 22:27:18 (+0000)  main      data = loadData(config["api"], config["journey"])
03.11.21 22:27:18 (+0000)  main    File "src/main.py", line 159, in loadData
03.11.21 22:27:18 (+0000)  main      journeyConfig, apiConfig["apiKey"])
03.11.21 22:27:18 (+0000)  main    File "/src/trains.py", line 171, in loadDeparturesForStation
03.11.21 22:27:18 (+0000)  main      Departures, departureStationName = ProcessDepartures(APIOut)
03.11.21 22:27:18 (+0000)  main    File "/src/trains.py", line 33, in ProcessDepartures
03.11.21 22:27:18 (+0000)  main      departureStationName = APIElements['soap:Envelope']['soap:Body']['GetDepBoardWithDetailsResponse']['GetStationBoardResult']['lt4:locationName']
03.11.21 22:27:18 (+0000)  main  KeyError: 'GetDepBoardWithDetailsResponse'
03.11.21 22:27:19 (+0000) Service exited 'main sha256_{removed in case this part is unique}_'
03.11.21 22:27:21 (+0000) Restarting service 'main sha256:_{removed in case this part is unique}_'
03.11.21 22:27:21 (+0000)  main  Starting Train Departure Display v0.1.1
03.11.21 22:27:26 (+0000)  main  Effective FPS: 0.0
03.11.21 22:29:47 (+0000)  main  Effective FPS: 18.61
03.11.21 22:32:07 (+0000)  main  Effective FPS: 18.63
```

mattanorak, 2021-11-19:
Seems to be fixed with the latest version.

Closed 2021-11-19.

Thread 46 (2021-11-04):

Raspberry Pi Zero WH maxes out at 100% constantly

mattanorak, 2021-11-04:
Looking in the dashboard, I see that my RPi Zero WH is constantly maxing out at 99-100% CPU and the effective FPS is anywhere from about 2.2 to 2.22 - consequently the refresh on the screen (when text scrolls) is very slow and jumpy rather than smooth as with the Pi3.  I also notice that the clock at the bottom sometimes misses a second or catches up after a pause (especially at the time when scrolling begins on the 'calling at' stations).

It could well be that the Pi Zero WH is just not powerful enough for this, but wanted to raise it in case it's something else causing an issue with this device.

This is only for the Pi Zero WH - the Pi3 is fine.

chrisys, 2021-11-05:
This is something that's bugged me for a long time, and I have had a few different debugging sessions with no real improvement. I did the original development work on a Pi 3 and like you found it to be a lot smoother, but had to sacrifice the performance for the convenient form factor of the Zero. However with the recent release of the Zero 2 I am hoping we can have the best of both worlds! I have one arriving in a few days and will put it to work in my sign when I get a chance.

mattanorak, 2021-11-06:
I've got one coming next week as well.  What device would it be under in Balena Cloud?

LeePorte, 2021-11-07:
I have a zero 2 and am seeing 78 - 82% CPU utilisation.

chrisys, 2021-11-09:
We're still working on adding the device type to balenaCloud but it shouldn't be too much longer. This is the issue to follow for updates: https://github.com/balena-os/balena-raspberrypi/pull/725

chrisys, 2021-11-09:
@LeePorte what effective frame rate does the code report in the logs when you're running on the Zero 2?

LeePorte, 2021-11-09:
I've seen highs of 17.91 and lows of 10.86

```
Nov 08 11:14:52 train-sign python3[2778]: Effective FPS: 10.86
Nov 08 11:14:52 train-sign python3[2778]: Effective FPS: 10.88
```

```
Nov 09 08:48:29 train-sign python3[10163]: Effective FPS: 17.9
Nov 09 08:48:29 train-sign python3[10163]: Effective FPS: 17.91
```

mattanorak, 2021-11-10:
Excellent - might give that a try while I'm waiting for the device type to appear on BalenaCloud (physical device arrived today).

LeePorte, 2021-11-10:
If it would help I can post up the systemd service file.

mattanorak, 2021-11-11:
Exellent - if you can!

LeePorte, 2021-11-11:
Here's my service file to use as a base

```
[Unit]
Description=Train Sign Service
After=multi-user.target

StartLimitIntervalSec=500
StartLimitBurst=5

[Service]
Type=idle
WorkingDirectory=/home/pi/uk-train-departure-display
Restart=on-failure
RestartSec=5s
Environment="TZ=Europe/London"
Environment="departureStation=<STATION_CODE>"
Environment="refreshTime=120"
Environment="screenRotation=2"
Environment="apiKey=<API_KEY>"
Environment="operatingHours=8-22"
Environment="screenBlankHours=1-6"
Environment="outOfHoursName=<STATION_NAME>"
ExecStart=/usr/bin/python3 src/main.py

[Install]
WantedBy=multi-user.target

```

mattanorak, 2021-11-11:
Perfect - thank you.  I'll give it a go later tonight on the Zero2 and let you know how I get on.

mattanorak, 2021-11-14:
Thanks, @LeePorte - For some reason I couldn't get the service file to work, so instead I edited config.py (I also had to put VERSION in the home directory (I think that was a Path statement thing though - or lack thereof).
What I did was just create a cron entry to run on boot and that did the trick.
Before I could get it to work, I had to do a few things like install the dependencies in the requirements.txt file, but that was easy!
Thanks for the tip!
Currently getting about 19.88 FPS standalone on the Zero2W.

mattanorak, 2021-11-15:
@LeePorte - Odd, I've noticed that this seems to stop running after a while (after 30 mins this morning).  I checked using:
`ps-ef |grep main`
and I didn't see the main.py process running as I normally do, so this seems to have terminated.
I am running the command with:
`python3 /home/pi/uk-train-departure-display/src/main.py &`
It's running in the cron as an @reboot, so rebooting fixes it - temporarily.

Anyt thoughts on this?

LeePorte, 2021-11-15:
I had seen some network timeouts that caused it to die. Though since using the systemd service file, I've not had that issue as it has restart on failure set.

I used the following to create and enable the systemd service file

```
sudo vi /lib/systemd/system/train-sign.service
sudo systemctl daemon-reload
sudo service train-sign start
```

What method did you use to try and install it?

mattanorak, 2021-11-15:
I seem to remember doing something similar (with nano, though, not vi).
what did you put in `train-sign.service`?

LeePorte, 2021-11-15:
Nano is fine, use your editor of choice

The contents of train-sign.service was the following with some of the details adjusted (<STATION_CODE>, <API_KEY> and <STATION_NAME>) to suit my info.

```
[Unit]
Description=Train Sign Service
After=multi-user.target

StartLimitIntervalSec=500
StartLimitBurst=5

[Service]
Type=idle
WorkingDirectory=/home/pi/uk-train-departure-display
Restart=on-failure
RestartSec=5s
Environment="TZ=Europe/London"
Environment="departureStation=<STATION_CODE>"
Environment="refreshTime=120"
Environment="screenRotation=2"
Environment="apiKey=<API_KEY>"
Environment="operatingHours=8-22"
Environment="screenBlankHours=1-6"
Environment="outOfHoursName=<STATION_NAME>"
ExecStart=/usr/bin/python3 src/main.py

[Install]
WantedBy=multi-user.target
```

It might we worth checking your python3 path with `which python3` and making sure it matches.

mattanorak, 2021-11-15:
Yep, I set python3 to run as default and in the script anyway, I call python3 ....
I also found that running it like this will also restart the process (I think) if it terminates:
`setsid python3 /home/pi/uk-departure-display/src/main.py < /dev/zero &> /home/pi/log.txt &`

Next, if this keeps terminating (which it seems to be OK up to now), I'll try belt and braces like this:

`!/bin/bash
if [ $(ps aux | grep 'yourscript.py' | grep -v grep | wc -l | tr -s "\n") -eq 0 ]; then /your/path/to/yourscript.py; fi &`

Messy, but it looks like it would work :-)

mattanorak, 2021-11-15:
OK, I got it working as a service now.  I'll see how long it stays up.  The only difference I used here (and that seemed to get it working) was instead of:
`After=multi-user.target`
I used:
`Requires=network.target`
and then in the main section I added:
`User=pi`

Fingers crossed....

LeePorte, 2021-11-15:
@mattanorak How's it been holding up?

LeePorte, 2021-11-15:
Interestingly CPU usage seems to be a little lower under Bullseye

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

mattanorak, 2021-11-16:
Seems to be OK - stayed up all yesterday and is still there this morning :-)
CPU seems roughly the same as yours.
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

Thanks for the assistance - will keep an eye on it and see how it goes.

chrisys, 2021-12-06:
Hey @LeePorte @mattanorak since balena now has support for the Pi Zero 2 I wonder if you guys have given it a try?

LeePorte, 2021-12-06:
I confess i have not. I've been working on the dual display. If I get a chance I'll give it a spin in the next few days.

mattanorak, 2021-12-07:
Hi - also not had chance to test.  I'll see if I can do that this week.  I've got a couple of Zero W 2's now and some spare memory cards, so if I get some time I'll give it a whirl.

chrisys, 2021-12-09:
Just a heads up guys, I haven't attached a display to my Zero 2 yet but I did try building the project for the Zero 2 and it fails. The way to get it to work at the moment is to set the default device type for the balenaCloud application to the Zero 1 (as you would have done before), then add a Zero 2 to the Zero 1 application. This way the builders build for the 32 bit architecture of the Zero 1 but it still runs on the Zero 2 (64 bit) as it's backward compatible. I will look into the changes necessary to update the project to make it build for 64 bit architectures.

chrisys, 2021-12-10:
Scratch that, it should work now due to the workaround in #56

LeePorte, 2023-07-07:
@chrisys I've just updated and it's running much faster. Possibly a bit too fast. Though that may just be me being used to how it was before. I'll try and grab a video.

mattanorak, 2023-07-08:
Must admit I've not tried it in the dashboard for a while, I've been running standalone - I'll plug my spare in and give it a go.

LeePorte, 2023-07-08:
Here's a [video of it running on a PI zero 2W](https://cloud.porte.uk/index.php/s/GSfhsPdpYqVnsci)

And the resulting htop

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

Definitely much lower resource use

chrisys, 2023-07-11:
@LeePorte oh wow that's definitely scrolling too fast for me! We might need to close this issue and start a new one for scrolling speed to fast now - whodathinkit!

LeePorte, 2023-07-11:
It's much easier to slow things down though!

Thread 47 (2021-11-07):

Multiple displays

LeePorte, 2021-11-07:
Hi,

What do you think about the option to have multiple displays? The Pi could support this as it has 2 i2c busses (https://github.com/rm-hull/luma.core/issues/55#issuecomment-286868008).

My use case is that I have a 2 platform station and would like to have one display for platform 1 and one display for platform 2.

LeePorte, 2021-11-23:
I've got it working on my fork

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

In the case of there being no platform assigned it is skipped in the filter until the train is assigned a platform.

Would there be any interest in raising a PR for this? As it is controlled by environment variables the single display behaviour is not affected.

chrisys, 2021-12-06:
@LeePorte absolutely! This looks really cool. I'm interested in seeing your implementation but otherwise have no objections to this feature being added. Again my apologies for the late reply as I've been offline for a couple of weeks.

LeePorte, 2021-12-06:
No worries about the time, real life is a thing we all have!

I've created https://github.com/chrisys/uk-train-departure-display/pull/54 for you to have a look at for my implementation. There is probably plenty of optimisation that can be done.

LeePorte, 2021-12-29:
All merged in so closing the issue. Thanks for taking the time to review the issue and the PR

Closed 2021-12-29.

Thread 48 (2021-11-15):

Issue with Balena deploy Raspberry Pi W 0

mbh-dev, 2021-11-15:
Hi,

I've been trying to deploy this app using balena to a Raspberry Pi 0 W, however there's either an issue with Balena to this app, as the Pi doesn't seem to boot and is not visible on the Balena dashboard.

Has anyone else experienced this issue?

Thanks.

Closed 2021-11-17.

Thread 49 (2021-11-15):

Service Restarting

AtomicLaser, 2021-11-15:
Installed everything as per the Belina import, changed the API code to my own and seem to hit an issue where the service constantly restarts after flashing up the **UKTrainDepartureDisplay - Powered by National Rail Enquiries**

Any ideas at all?

Here's a log which repeats in the log

Service exited 'main sha256:b7e488964f2c1fee59caa39981ce41314fa040bdfb029ec29813c7017e15ddae'
Restarting service 'main sha256:b7e488964f2c1fee59caa39981ce41314fa040bdfb029ec29813c7017e15ddae'
 main  Starting Train Departure Display v0.1.1
 main  Effective FPS: 0.0
 main  Traceback (most recent call last):
 main    File "src/main.py", line 336, in <module>
 main      data = loadData(config["api"], config["journey"])
 main    File "src/main.py", line 159, in loadData
 main      journeyConfig, apiConfig["apiKey"])
 main    File "/src/trains.py", line 171, in loadDeparturesForStation
 main      Departures, departureStationName = ProcessDepartures(APIOut)
 main    File "/src/trains.py", line 33, in ProcessDepartures
 main      departureStationName = APIElements['soap:Envelope']['soap:Body']['GetDepBoardWithDetailsResponse']['GetStationBoardResult']['lt4:locationName']
 main  KeyError: 'soap:Envelope'
Service exited 'main sha256:b7e488964f2c1fee59caa39981ce41314fa040bdfb029ec29813c7017e15ddae'

AtomicLaser, 2021-11-16:
Managed to resolve this, I was following the blog on the balena website which details to get a TransportAPI key.  Having looked into it these instructions are old and you now need to get an API key from NRE, all is working apart from another issue  which I'll post separately.

AtomicLaser, 2021-11-16:
Closing

Closed 2021-11-16.

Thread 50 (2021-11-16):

GPIO Issue - Channel already in use

AtomicLaser, 2021-11-16:
Hey all, having got this working, I am now having an issue with a GPIO warning - Logs below if anyone knows how this can be resolved?

I am running on a Raspberry Pi3

main  Starting Train Departure Display v0.1.1
 main  /usr/src/python-packages/luma/core/interface/serial.py:200: RuntimeWarning: This channel is already in use, continuing anyway.  Use GPIO.setwarnings(False) to disable warnings.
 main    self._gpio.setup(pin, self._gpio.OUT)

mattanorak, 2021-11-19:
I think it's quite normal if the program has already been running and you're running it again.  As far as I recall, unless it doesn't start, you can ignore it, but I'm prepared to stand corrected.

chrisys, 2021-12-06:
What @mattanorak says is my understanding too; we can probably handle this in a more graceful manner but as it stands I've seen the message a lot but it's never actually caused an issue. I'll leave this issue open as a reminder for us to do that :)

AtomicLaser, 2021-12-06:
FWIW, my original issue with this is that the screen blanked at the same time as the log message and would not resume.

After doing some investigation, I think there was an issue with the solder blob on the 4SPI jumper, so after fixing that I've not had any other issues, although as noted, it still does show up in the logs from time to time without any further issue.

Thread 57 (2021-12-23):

Ease of use, UX, kits, open fleets, and more!

chrisys, 2021-12-23:
I've had a few people contact me wondering if there are kits available, as well as people giving these as gifts to non-technical friends/family members for novelty and practical reasons.

I have been thinking of ways how to make this easier for people. Some things to investigate:

1. Consider adding [WiFi Connect](https://github.com/balenablocks/wifi-connect) to the project to allow dynamic setup of the device's WiFi connection when it's shipped to a new location.
2. Implement a basic web interface to allow the settings to be changed without requiring a balena login
3. Use an open fleet on [balenaHub](https://hub.balena.io) to simplify the process of deployment (requires 2. to be in place)
4. Update 3D printed case to be easier to print and assemble - use positive fixings (i.e. screws) for screen and Pi, remove the need to print with so many supports and ease tolerances on screen fitting.
5. Make kits of parts available - e.g. everything required except the Pi, including a pre-flashed SD card.
6. Consider a solder-free assembly path, perhaps some kind of adapter PCB with pogo pins

These are a bunch of ideas I've been thinking about to address the various pain points I've seen people encounter over the past couple of years. I'd like to continue developing the project and allow more people to build these displays, so if anyone has any input or if anything particular in the above list sounds good, let me know!

jimmykl, 2024-12-05:
Not sure how/if this is active any more but a vote for 1 ✋

I'm going to send one to some friends overseas and even with their wifi password it'd be much neater if they could set it up themselves (especially if they move, change router or network name in the future…)

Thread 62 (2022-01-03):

Create alternate platform layout

chrisys, 2022-01-03:
![Uploading platform_sign.png…]()

I noticed today that some platforms have a sign which shows more information about the layout and carriages, this is a reminder to look into the possibility of replicating that.

LeePorte, 2023-10-18:
I also spotted this layout for less advanced stations this morning.

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

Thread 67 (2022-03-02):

Departure board on steroids....

Stavrosi, 2022-03-02:
Hey Chris, hope you're keeping well chap.

I stumbled across your awesome Pi train departure board project after a random conversation with a mate over the weekend. It got me thinking that it would be very cool if I could, for his birthday, make him a nice display to go on the wall of his pub to display the train times (his pub is right next to our local station). However, to make this useful, it would need to have a much bigger screen attached to it (something like an 11.9" HDMI connected panel for instance). My fear here is that simply outputting the data to an "normal" screen would mean it would lose all of it's authenticity therefore, a larger matrix style screen would really make it pop!

I've seen (in the comments) someone else asking about this however, with my very limited knowledge, I'd have no chance of getting it working with a different type of display. To this end, I was just wondering if you were aware of anyone who may have already tackled this or, perhaps there's someone you know that could maybe take a look at it?

Kind regards,

Steve.

chrisys, 2022-03-02:
Hey Steve, that sounds like an awesome project!

What's your experience like with assembling electronics? Could we use something like this? https://www.amazon.com/Indoor-128x64-Module-256mm128mm-256128mm/dp/B0869P1DCH

I think it would be possible to use 2 of the above to create the same 256x64 matrix as the small OLED screen, and make something pretty awesome to go in the pub. The above would give you a 500mm wide display. If you're up for it I'd be willing to figure out what would be the right panels to get and make sure the software works with them, but of course the assembly and hardware side of things would be up to you. Honestly there may even be a cheaper version as that one is full RGB and we obviously only need one colour.

Using HDMI monitors is possible - you'll note there's an open PR in the repo on GitHub which adds this, but I don't think it looks anywhere near as impactful, and I've been resistant to merge the changes into the project as it adds a lot of bloat to the software.

What I would ask though is that we move the discussion to an issue on the GitHub repo so everything is in the open and other users of the project can see and contribute as well though.

Let me know your thoughts.

chrisys, 2022-03-03:
I ended up ordering a couple of those displays, I'll give it a try when they turn up and see how it works out 👍

Stavrosi, 2022-03-03:
Morning Chris, thanks for the update.

I’m inclined to order a pair also so that I can get to work on an enclosure to suit the panels as soon as they arrive.

Thanks again,

Steve.

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

chrisys, 2022-03-03:
Up to you Steve but no guarantees we can get it working at this stage, I mean to a certain extent it's just software so I am sure we can figure something out, but you may want to hold off.

chrisys, 2022-03-23:
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

Hey @Stavrosi I got a proof of concept going! Will work on polishing it up and making relevant PRs. 👍

GOTO-GOSUB, 2022-03-23:
Now that is looking good.

chrisys, 2022-03-23:
It looks so good! There's something oddly satisfying about miniaturising something then making a bigger version of it again 😂

It's all relatively simple stuff, the main piece of work is adding support for these displays to the luma.led_matrix library (for which I'm creating a PR), then some minor tweaks to this project to utilise that.

A note for @Stavrosi though, you'll probably need a board like this: https://github.com/hzeller/rpi-rgb-led-matrix/tree/master/adapter/active-3

I've connected the displays directly to the GPIOs on a Pi 3 for testing but get some flickering. I am assuming this will be resolved by one of the above boards, so I have ordered boards and parts to make a few. If they all work OK I'll happily offer any extras to people building this project for parts + shipping costs.

chrisys, 2022-04-06:
@Stavrosi my PCBs and parts for the active-3 board are due to arrive within the next few days - do you want me to assemble an extra board and ship it to you for testing?

chrisys, 2022-04-18:
PCBs arrived at last! Still waiting on components.

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

chrisys, 2022-05-18:
At last my component orders have arrived so will put together some boards and keep testing. Do you need me to send you a completed board if it works OK @Stavrosi ? I have 5 PCBs so much more than I need :)

mattanorak, 2022-06-13:
Hi @chrisys - Just wondering how you're getting on with this.  I'd be interested in a kit list and instructions for putting one together if you've got it working.
Is that a colour LCD board?  If so, are you planning on multi colour or just the one colour?

chrisys, 2022-07-01:
@mattanorak sorry I've not had a chance to push this forward any more yet, but yes it is an RGB LED matrix panel, so in my proof of concept had coded it so you can specify the colour of the display with an environment variable (single colour).

Stavrosi, 2023-07-27:
Wow, it feels like so long ago that we first started chatting about all of this. I had to go away with work for a few months and completely lost the thread on this when I returned. I'd still very much like to get the large format up and running - it seems that stock of Pi Zero 2W's is now levelling out a little so just ordered one too.

mattanorak, 2023-08-23:
I’ve got a couple of spare PIs in and I’ve also got 3x P5 full colour LED boards and connectors.  Happy to test along - what else is needed?MattMatt NewtonOn 27 Jul 2023, at 16:09, Stavrosi ***@***.***> wrote:
Wow, it feels like so long ago that we first started chatting about all of this. I had to go away with work for a few months and completely lost the thread on this when I returned. I'd still very much like to get the large format up and running - it seems that stock of Pi Zero 2W's is now levelling out a little so just ordered one too.

—Reply to this email directly, view it on GitHub, or unsubscribe.You are receiving this because you were mentioned.Message ID: ***@***.***>

christopherpm, 2023-10-03:
If the large version works, please post details - I'd love to build it!

chrisys, 2024-04-01:
Sorry guys some stuff came up; I still have all the hardware for this and do intend to get back to it one day!

If anyone wants to hack on it though all you need is here: https://github.com/rm-hull/luma.led_matrix/pull/275
And here: https://github.com/hzeller/rpi-rgb-led-matrix/blob/master/wiring.md

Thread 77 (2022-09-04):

Unhandled exception when internet is down

stephenhibbert, 2022-09-04:
I have a flakey internet connection at the moment - when it's down I get an unhandled exception (see [error.txt](https://github.com/chrisys/train-departure-display/files/9484165/error.txt) attached). Workaround is to specify `Restart=always` in the systemd service but maybe there is a better way to handle

P.S. the project is awesome, thanks for porting to the free national rail API.

BeauAgst, 2023-02-12:
Hey @stephenhibbert, I found myself running into this issue too. I personally have my fork of this running directly on my Pi as I found that I got a higher FPS.

The PR I've put up will revert the display to the "Out of hours" screen if connection fails to the OpenLDBWS service, and continue to try and make requests on each refresh as normal.

@chrisys what do you think on this? Does it seem like an acceptable approach?

Closed 2023-02-18.

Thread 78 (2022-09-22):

If set to station WBQ, screen is often blank, even after reboot.

mattanorak, 2022-09-22:
Odd one to track down the issue, but if I have the board (running locally) set to WBQ as the station, it can work fine for a while, but then the screen will go blank.  It will appear to cycle through the start screen a couple of times and then remain blank.
Rebooting the Pi goes through the same cycle.
If I change the station to anything else, it seems fine.

Not sure where to look for logs to see why nothing is showing - any tips appreciated.

chrisys, 2022-10-24:
@mattanorak you should be able to use the logs output in the balenaCloud dashboard - for example in #77 the logs were shared (which I have a hunch is probably related).

mattanorak, 2022-10-24:
I'll give that a try - thanks.  I suspect it's the Pi Zero's Wi-Fi going to sleep and not recovering properly, but will try this.

Thanks.

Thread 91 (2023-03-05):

Fails to build

Dreadmond, 2023-03-05:
I get this error message when I try to update with the Balena button in the Getting Started page:

[Info]     Starting build for uk-train-departure-display, user *********
[Info]     Dashboard link: https://dashboard.balena-cloud.com/apps/******/devices
[Info]     Building on arm02
[Info]     Pulling previous images for caching purposes...
[Success]  Successfully pulled cache images
[Info]     Starting to build main
[Info]     Uploading images
[Success]  Successfully uploaded images
[Error]    Some services failed to build:
[Error]      Service: main
[Error]        Error: The command '/bin/sh -c install_packages apt-rdepends' returned a non-zero code: 100
[Info]     Built on arm02
[Error]    Not deploying release.

chrisys, 2023-03-21:
@Dreadmond can you confirm if 1. this is still a problem and 2. if it is, what options you're choosing after you reach the balena dashboard?

The project is test-built whenever a change is made and I've just double checked by following the flow using the button in the getting started guide and everything seems to work OK so I'm wondering if it was just an interruption in the balena build service or something.

Closed 2023-04-04.

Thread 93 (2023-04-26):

Getting 3 dots on the left of the display and no departures are showing.

ISC82, 2023-04-26:
So I did this build a few weeks ago and it has been working flawlessly. I am happy with it I am thinking of getting myself a 3D printer so I can create a few and gift to friends and family. However, today it started showing 3 dots on the left of the screen and no departures are being displayed. It is still showing the "Welcome to [My local station]" and the time is correct and updating. Diagnostics is showing no errors. I tried lots of other station codes with the same result on each. I even re-imaged the build to a different SD card but get the same result. This has been for at least the past 12 hours. Any suggestions?

I have posted a screenshot on my Twitter.

https://pbs.twimg.com/media/FurM7sAWYAADxKd?format=jpg&name=small

ISC82, 2023-04-26:
Here are the logs after a reboot.

26.04.23 22:57:52 (+0000)  main  Starting Train Departure Display v0.4.0
26.04.23 22:57:52 (+0000)  main  /usr/src/python-packages/luma/core/interface/serial.py:206: RuntimeWarning: This channel is already in use, continuing anyway.  Use GPIO.setwarnings(False) to disable warnings.
26.04.23 22:57:52 (+0000)  main    self._gpio.setup(pin, self._gpio.OUT)
26.04.23 22:57:58 (+0000)  main  Effective FPS: 0.0
26.04.23 22:59:59 (+0000)  main  Effective FPS: 11.74
26.04.23 23:02:00 (+0000)  main  Effective FPS: 11.68
26.04.23 23:04:01 (+0000)  main  Effective FPS: 11.5
26.04.23 23:06:02 (+0000)  main  Effective FPS: 11.47
26.04.23 23:08:03 (+0000)  main  Effective FPS: 11.43

GOTO-GOSUB, 2023-04-27:
I get this if my display is on outside of the active hours (screenBlankHours variable) that I have set or if the trains are on strike again. I've also seen it on stations where the trains are very infrequent such as the Eurostar where the departure data does not appear to be provided all through the day. Assuming your choices of station have trains running at that time of night, may I suggest checking that you aren't running it outside of your active hours setting ?

ISC82, 2023-04-27:
Thanks for this. I checked those variables and they were correct. However, you made me think about some of the other variables and I then realised I had set the destination station. I cleared that and the departures started appearing again. So it seems that trains were being diverted to a different station in the past 48 hours.

So lesson learned, check and double-check those variables first. Would have saved me a lot of wasted troubleshooting last night.

GOTO-GOSUB, 2023-04-28:
Cool, it's good to know you've fixed it. Thanks for the update as well since it might help someone else in future.

chrisys, 2023-05-08:
Thanks for helping here @GOTO-GOSUB ! Just to clarify, the reason that it does this is because that's what the signs say in the middle of the night when there are no trains (i.e. out of hours, or your filters have been set as in this case).

At least, this is what they used to look like last time I was waiting at a station in the middle of the night 😅

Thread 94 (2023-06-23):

KITS AVAILABLE! 😮

chrisys, 2023-06-23:
Hey all. I have produced a handful of kits which I want to make available to help out those that don't have a 3D printer or easy access to get the display. Please don't expect perfect commercial 3D printing service quality but rather that of someone just trying to help out, so the parts might need some finishing work and will have minor blemishes.

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

**They'll include:**
* Front housing
* Rear cover
* Desk mount option
* Hanging mount option
* 2 display clips
* Yellow or White OLED display (with the headers removed from the board so it will fit in the case)
* Screws
* Pre-cut USB power cable
* Handful of small wires in the right colours to match the documentation

**You need to provide your own Raspberry Pi Zero 2 W and SD card** - as much as I'd like to include these I can't get hold of them easily either! Assembly will require some basic electronics hand tools as per the instructions [in the documentation](https://github.com/chrisys/train-departure-display/blob/main/docs/01-getting-started.md).

**As of 21st July 2023 I have no kits left** - they all went fast, I'll work on getting another batch ready.
When these are gone I have no idea if there will be more. I think a fair price for this initial test batch is £50 + postage to wherever. If you are interested in one from a new batch email me on chris@thefnet.co.uk and we'll figure out the details.

mattanorak, 2023-07-27:
If you ever do the kit without the screen that would be great.  Wouldn't mind putting mine in a case like that.  I tried to make a plexiglass cover - doesn't look bad, but it's not 100%.

chrisys, 2023-08-21:
@mattanorak send me an email with what parts you need - if it's literally just the 3D prints I might be able to help out, but I've run out of screens, wires, and USB cables (I think)

ruudvddries, 2025-02-23:
This one should work, right? https://nl.aliexpress.com/item/33012440441.html

> Not exactly the right place to post [@chrisys](https://github.com/chrisys) but didn't want to open a new issue. The Aliexpress link to the screen example no longer works, if you can find another suitable that would be handy, thanks. edit: Whilst looking (seems hard to find anything in stock that looks right) I noticed 3.12" seems more common? Guess it could be scaled up a little...

pauljrowland, 2025-03-05:
Getting there - just printing a deeper version of the screen as I've already destroyed one display taking the header off (the metal pads dropped out leaving just a hole with nothing to solder to 🤣 🤣) so decided to leave them be on this attempt.

Really cool little project

https://github.com/user-attachments/assets/20f89390-8be5-4161-987b-7d9abe5a639f

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

Closed 2025-06-10.

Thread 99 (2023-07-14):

Add in delay reason

MatthewAscough, 2023-07-14:
The API can report a delay reason when a service is delayed - this could be added after the TOC/carriage information

CalamityJames, 2023-07-19:
This is something I was also considering. I've been hoping that a delay occurs when I'm getting on a train so I can see how it is displayed on a real display, for some reason it's quite hard to find examples of these displays in action on YouTube!

chrisys, 2023-07-21:
@CalamityJames things that totally identify you as an "enthusiast", no sane person would ever say: "I've been hoping that a delay occurs when I'm getting on a train" 😆

Presumably it's ENUM('Leaves on the line','Cows on the line','Driver is at the wrong end of the line','Someone said it might snow next Thursday')

MatthewAscough, 2023-07-21:
(un)fortunately? there’s delays on southeastern today cos of a broken track so i’ll try to find one on my way into work. i believe though it shows it after the carriage information so would be “— a thameslink service which has 8 coaches. — this train has been delayed by urgent repairs to the railway” but the API returns the full “this train has been delayed…” message so you can just pop that straight in after the hyphens

CalamityJames, 2023-07-21:
See I've been studying a few of my local stations (also Southeastern) and it seems there is no defined way of displaying this information.

Some show the delay info on a second scrolling message after the calling points. I think some do it other ways.

In fact the whole layout tends to vary from station to station. I could spend months making different layouts for different stations 😂

**East Farleigh**
_Smaller display as it's a tiny station, also coach information is in the top right and alternates between that and "On time" etc):_
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

**West Malling**
_Doesn't show the "1st" for next train, but DOES show 2nd. Also coach information appears top right again_
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

**Tunbridge Wells**
_Coach information shown in second scrolling line_
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

chrisys, 2023-07-21:
I wonder if these have all been made by different suppliers under different contracts over time depending on when the stations have been refurbished/updated. As for layouts the one I'd really like to add is an Underground one - with the cool alternative font (and different API).

CalamityJames, 2023-07-27:
I got a delay today! 🥳

https://github.com/chrisys/train-departure-display/assets/5637797/d6b2a38b-d90a-4db8-86b3-dca2774f5fa1

It does seem like it's added as a new line, which complicates things a bit as I've been trying in vain to do that "pop up scrolly thing" in more than one place already.

I need to do some more researching into how Luma works I think!

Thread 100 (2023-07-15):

Debug screen

stephenhibbert, 2023-07-15:
Spotted this debug screen today at Greenwich station, could be cool to have something similar to display the IP address on boot.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

CalamityJames, 2023-07-21:
I've created a mockup of this which seems to work well.

I have no idea what some of the codes on this screen signify, but here's what I've replaced:
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

1 = Current station code set in config
2 = Platform (shows PlatAll if no platform set) (todo: have different platform based on screen)
3 = Current version of Train Departure Display
4 = Today's date (can't think of an easy way to get the build date of the software without adding a new file)
5 = IP address

The next decision is **when** to show this. Open to suggestions here, especially from @chrisys !

I wondered about replacing the splash screen if a debug mode is enabled, or maybe even having a debug flag that leaves this screen on constantly.

chrisys, 2023-07-21:
Wow @CalamityJames I was just trying to clear my plate so I could have a look at this ticket this afternoon! This is great!

Here are my thoughts:
* I like your idea of a debug flag to show it, maybe something like if the var is set to TRUE it's always on but if it's an integer we show it on startup for that number of seconds? That feels like it would handle a decent amount of what people might want to do with it.
* My preference would be to remove information that doesn't mean anything in our scenario, but retain the look and feel, so maybe something like...
* Display = "<departureStation>[-><destinationStation>](Plat<platform>) <refreshTime>s <operatingHours>" so we'd end up with something like 'PAD->HWV (PlatAll) 120s 8-22h'
* Script = VERSION (I think we can just stick with the version here, as you say, date is a bit hard to do for the source, and I think today's would be misleading). Another option would be to get the build date of the current release from the balenaCloud API.
* Address = device MAC address? UID = balenaCloud device UUID (first 7 chars from BALENA_DEVICE_UUID), IP=local IP

What do you think?

CalamityJames, 2023-07-21:
Something like this? 😁
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
(After putting a MAC address in I don't think there's room for UID)

Also, here it is without some extra options just for completeness
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

chrisys, 2023-07-21:
@CalamityJames looks great to me!

Closed 2023-07-22.

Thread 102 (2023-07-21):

In some stations filtered platform data is incomplete due to only 3 rows being returned from the API

CalamityJames, 2023-07-21:
Due to the National Rail API not supporting a native platform filter, it is done in the script. With [rows set to the default of 3](https://github.com/chrisys/train-departure-display/blob/f92c26dd3237cfcc49dd7c0f4a1a5e92828260ab/src/main.py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) and a platform filter in place, this sometimes returns less information than is actually available from the API, for example:
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

Upping the `rows` to `10` (which is actually the upper limit for this API request) fixes that issue:
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

My proposal would to just get as much information from the National Rail API as is available. I can't see it being too much of a performance hit, but thought I'd log this as an issue rather than just submitting a PR just to see what your thoughts were!

chrisys, 2023-07-24:
Agree @CalamityJames I don't see why not!

Closed 2023-07-26.

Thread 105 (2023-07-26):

Major disruption at Paddington causing crash

jruys, 2023-07-26:
“Major disruption” at PAD today. That’s the station my board is showing and (I guess) somehow the software doesn't like what its getting from the API.

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

jruys, 2023-07-26:
Update: 2 minutes later board started running again, all 3 entries showing “delayed” or “cancelled”.

CalamityJames, 2023-07-27:
I believe I have added a `try` block for this error, however as it doesn't happen that often there isn't much real world testing that can be done here!

I made a few changes to how the `drawBlankSignage` function works, allowing it to display that there has been an error parsing the data, if the newly added debug mode is enabled.
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

If debug isn't enabled, it falls back to the Out of Hours station name, as we can't fetch the actual station name as there has been an error getting data from the API.

I did originally show this error message at any time, but I would imagine real departure displays wouldn't be verbose unless there was a debugging mode enabled, so added an if for debug.

It also should log the error to the console too.

I did consider writing a routine to temporarily speed up the `refreshTime` if an error like this occurs, but that might be out of the scope of this bug so decided against it for now!

I haven't submitted this a pull request yet, but feel free to check out the changes on my branch: https://github.com/CalamityJames/train-departure-display/tree/handle-openldbws-error

Will wait for @chrisys input to submit a PR!

BeauAgst, 2023-07-27:
Can I suggest that if we go down this route we put it behind a config? I'd much prefer my display to not update so that there's a more graceful degredation

CalamityJames, 2023-07-27:
That's a fair point, as it stands I think that by the point the loop has got here the old departure data will have been unset, I will try to have a play around this evening to see if there's anything that can be done

CalamityJames, 2023-07-27:
@BeauAgst I have added a variable that gets written to each time there is good data which can be used in the event of API failure.

I left the original error handling in, in case the display gets started and there is no good data at all

https://github.com/CalamityJames/train-departure-display/commit/e73754a60ae23603fca44d9108c2e4fbfadc4231

chrisys, 2023-08-21:
I think I'm of the view here that if we have good data (even if outdated) we can show it, but like you say if we start the display and there's no good data at all it's good to show the error message.

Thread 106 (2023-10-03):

firstDepartureBold variable not working

christopherpm, 2023-10-03:
Hi,

First of all, thank you for this project. I have just this week built a departure board using the instructions at balena.

One thing not working for me though - I have set **firstDepartureBold** to **false**, but the first departure still shows in bold.

Regards,
Chris

christopherpm, 2023-10-26:
Just to add to the above. I commented out lines 407 and 408 of main.py on the device and rebooted. The first line then wasn't bold. However, as soon as I change a variable in Balena cloud and save the changes, the main.py on the device reverts to the original and once again the first line is in bold.

christopherpm, 2023-10-26:
I have discovered the issue! All of the true / false flags in the variables are set to lower case. Python is case sensitive and expects the first letter of a True of False flag to be capitalised.

As soon as I changed the variables to either **True** or **False**, things started displaying as I would expect.

Closed 2025-06-10.

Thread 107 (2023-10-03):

Screen glitch

mrglennjones, 2023-10-03:
Hi, my oled shows the boot up screen ok but then displays this static glitched layout.

I've tried another pi and it's the same.

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

mrglennjones, 2023-10-03:
Resistor at R5 wasn't quite connected

Closed 2023-10-03.

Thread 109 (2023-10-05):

Feature Request: London Underground Departures

mrglennjones, 2023-10-05:
would it be possible to add london underground departures times please?

LeePorte, 2023-10-18:
Those aren't available on the National Rail API unfortunately. TfL does have a pretty good API and you could certainly make a fork of this repo to query that API.

https://github.com/theodi/going_underground may be closer to what you need in this case.

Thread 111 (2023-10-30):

GPIO In Use Error

leacho73, 2023-10-30:
Hi,

I've got 2 separate PI Zero 2 devices running in my fleet, both cabled as per the instructions - one of them works perfectly, and one has a garbled display - checking the logs I am seeing:

/usr/src/python-packages/luma/core/interface/serial.py:203: RuntimeWarning: This channel is already in use, continuing anyway.  Use GPIO.setwarnings(False) to disable warnings.

Any idea how I can diagnose this? I'm not that familiar with Balena OS. I've double checked the connections and all appears as per the instructions - I have noticed however that the PI that doesn't work is red hot. I've tried re-flashing the PI but still the same issue.

Thanks :)

CalamityJames, 2023-11-14:
Interestingly I received a DOA Pi Zero 2 a few months ago which ran incredibly hot (I didn't even get to the stage of testing a screen with it).

In the end I got a replacement and it was all fine. I have a feeling it was an issue with the wifi chip as that was dropping out too - I documented some of it on the Balena forums as I wasn't sure if it was an OS issue or not: https://forums.balena.io/t/pi-zero-2-w-losing-wifi-ip-address-and-crashing/368274/

I think the GPIO in use issue is a common recurrence with this project, the advice is usually to ignore it: https://github.com/chrisys/train-departure-display/issues/50

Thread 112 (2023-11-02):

unable to boot Pi

rpring01, 2023-11-02:
I have tried flashing several times using different SD cards, the Pi doesn't seem to boot and never shows up in balena dashboard. i just get the led flashing 4 times then pause and repeat. I have tried to boot with raspberry pi os and that is ok so pi should be fine its a new zero 2 w.

Edit, its working now it was an issue with my wifi network.

Closed 2023-11-04.

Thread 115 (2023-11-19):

Add RealTimeTrains API

daveh6475, 2023-11-19:
Is there a simple way I can switch to using the RTT API rather than the National Rail one? Happy to mess around with the code a bit but don't want to mess the whole thing up for me!

chrisys, 2024-04-23:
This one was forked when everyone was using Transport API (until they imposed usage limits), we went with National Rail as I think it was the best option at the time.

Are there any big benefits to using RTT instead (outside of implementation practicality)? I'm not against moving over (or providing a choice for everyone) if the benefits outweigh the effort.

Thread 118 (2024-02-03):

Successful use of 5.5" OLED (documentation)

jruys, 2024-02-03:
Felt like using a larger display so ordered a 5.5" OLED from Ali.

Happy to report it works once you remove resistor P8080 to put it in 4SPI mode.

Connector is different from the smaller display but signals are clearly marked.

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

bonstio, 2024-02-03:
I'm inspired! Would you mind sharing a close up of the wires please?

jruys, 2024-02-04:
Let me post the Raspberry Pi pins to connect. Pi pin locations are listed in https://github.com/chrisys/train-departure-display/blob/main/docs/02-connecting-the-display-to-the-pi.md

Display - Raspberry

GND - 6
VCC - 1
SCL - 23
SDA - 19
RST - 22
DC - 18
CS - 24

Don’t forget to remove the resistor at P8080 otherwise display will not work.

bonstio, 2024-02-05:
Awesome. Thanks!

Closed 2024-02-04.

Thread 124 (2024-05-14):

Pretty sure this is NOT a code issue...

ScottTheHippy, 2024-05-14:
but damn.  After months of reliable enjoyment of my train departure display, I've entered into a peculiar realm where I'm killing Zero 2 W boards as fast I can order them.  I've tried different power- it all tests per spec.  Might the OLED be doing something toxic?  Has anyone seen this kind of weirdness?

I expect not- so point, laugh, and close the issue if you wish.  I might be losing my marbles.   Cheers!

chrisys, 2024-10-31:
@ScottTheHippy I haven't heard of this in relation to this project but I have myself killed Pis in the past by accidentally shorting the power supply pins on the 40 pin header. I'll leave this open for now in case anyone else can chime in but I'd check for shorts on the power lines going to the display (whilst it's not connected to the Pi). For what it's worth I've got a couple of units that are both very old now -- from the very start of this project, and they're still going strong, so no long-term issues to report. Not even screen burn in as some were suggesting!

chrisys, 2025-06-10:
Will close for now (cleaning up issues) but feel free to reopen if anyone has any further experiences or input to share.

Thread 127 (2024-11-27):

Enhancement suggestions

mattanorak, 2024-11-27:
Hi there,

Just looking at the displays on my desk and I thought it would be great if:

- We could randomise the station every x minutes (selected by user)
- Every so often, where the time is, the name of the station selected pops up for a few seconds, and then goes back to the current time (switching interval configured by user)

Just a couple of thoughts!
Cheers.
Matt

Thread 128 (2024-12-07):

Display not functioning at all

novpaul, 2024-12-07:
Chris. first of all I wanted to say thank you for all of your work on this. This is my first Raspberry Pi project and I was inspired to do it by your work, so thank you. As a result I am a complete noob to Raspberry Pi, I hope this question isn't too tedious for you as it may be very basic.....  I have followed the instructions to the tee and believe I have the screen connected correctly, I have also tried moving R6 to R5. I am getting nothing from my screen, not any type of indication that it is functioning. The Pi is on (green light) and hopefully you can see from the attached that it is connected in Balena Cloud and operational.

Is there something I am missing? Should I at least be getting some signs of life from the screen? I've no reason to think it's broken  as it's brand new. Is there a simple test I can do to check if the screen is working? Any advice would be super appreciated, really want to make this work.

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

novpaul, 2024-12-07:
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

novpaul, 2024-12-07:
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

bonstio, 2024-12-08:
Check your wires. Then check them again. Then re-do your soldering. Then try a new screen. I've built 10 of these beauties. One of the screens was either defective or I managed to trash it whilst soldering.

Good luck.

jruys, 2024-12-08:
First of all - what a great problem description! Not simply “it doesn’t
work” but stating what you already tried and clear pictures - bravo!

Can you get us a picture or double check the R5…R8 area? That got me a few
times. Those resistors are 0 ohm, so a blob of solder to bridge R5 and R8
should suffice. R6 and R7 should be open.

In the Balena console there’s a “logs” section under your device summary.
Anything interesting there when you (re)start the service?

Some other config things that caused my screen to go blank:

- “Dualscreen” was inadvertenly set to “true” and somehow that broke my
setup. That was a while ago, think that’s not an issue anymore.
- Time zone on my config was wrong which made the time fall within
“screenblankhours” which is when the screen is off! Mine is set to “22-7”
and TZ “Europe/London”.

Good luck!

JW

novpaul, 2024-12-08:
> Check your wires. Then check them again. Then re-do your soldering. Then try a new screen. I've built 10 of these beauties. One of the screens was either defective or I managed to trash it whilst soldering.
>
> Good luck.

Thanks so much for the reply, the board came pre soldered with pins so I (hope) it's not a soldering issue. Is there a way that I can know if the screen is working, I'm a complete beginner so, for example, once the power is attached and the wiring is correct should I see some sign of life from the board even if it is fuzz or just lit up etc? Or can there be a software configuration problem i.e the screen will be black until the raspberry pi is configured correctly?

Someone mentioned to me that sometimes the raspberry pi is preconfigured to the hdmi port and so that needs to be changed? Or should it be the case if I followed Chris blog step by step out of the box that the display should work?

You're help is really appreciated.
P

novpaul, 2024-12-08:
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

Thank you also!

Do these pictures help?

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

novpaul, 2024-12-08:
This is what I'm getting from the log below.

Just as an fyi I really am a beginner so even the most basic terms like leaving something "open" etc might have to be explained in laymans terms! Or even where the solder is supposed to go.

I keep getting "key error soap Envelope" in the log if that means anything.  Thanks so much

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

jruys, 2024-12-08:
I suspect there's something funky in your config - this is what mine shows on startup:

  Starting service 'main sha256:c41086cab1b98803fd20545d360830f14832dabadfb1dd87b701a714a3157097'
  Started service 'main sha256:c41086cab1b98803fd20545d360830f14832dabadfb1dd87b701a714a3157097'
  Releasing update locks
   main  Starting Train Departure Display v0.5.4
   main  /usr/src/python-packages/luma/core/interface/serial.py:206: RuntimeWarning: This channel is already in use, continuing anyway.  Use GPIO.setwarnings(False) to disable warnings.
   main    self._gpio.setup(pin, self._gpio.OUT)
   main  Effective FPS: 18.06
   main  Effective FPS: 19.0
   main  Effective FPS: 19.31

Yours seems to be unhappy about something in the config variables - it exits before the screen gets activated which would explain the blank screen.

Double check the "configuration" section? https://github.com/chrisys/train-departure-display/blob/main/docs/04-configuration.md

Re the screen - the interesting bit is what Chris shows in his manual [here](https://github.com/chrisys/train-departure-display/blob/main/docs/images/display-config-jumper.jpg) - the bits marked with R5 and R8 should have a R0 resistor in there, but a short piece of wire or blob of solder should do equally well. The bits marked R6 and R7 should have nothing between them (hence "open").

jruys, 2024-12-08:
...Probably not relevant but I'm confused - your log shows software version v5.5, I'm running v5.4 which as far as I know is the latest.

You did deploy with the big "deploy with balena" from the "installation" section of https://github.com/chrisys/train-departure-display/blob/main/docs/01-getting-started.md

Anyone else reading along: is there a 5.5 version?

metacurb, 2024-12-08:
Without being able to see the entire error, I would guess that your API details are invalid. The code is trying to reference fields in the API response that don't exist. Can you check your `apiKey` is set correctly, with no spaces and is in the right format?

metacurb, 2024-12-08:
You'll want to follow the final step in the docs - https://github.com/chrisys/train-departure-display/blob/main/docs/04-configuration.md

jruys, 2024-12-08:
> FYI @jruys , 0.5.5 is the latest version - https://github.com/chrisys/train-departure-display/blob/main/VERSION

Thanks @metacurb! Re-deployed and I’m now running v0.5.5. Looks like Balena still thinks it’s 0.5.4 though as it built it as a v0.5.4+rev1 version, probably something in a config file. Will check and file an issue if it’s not at my end.

jruys, 2024-12-09:
@novpaul The API key lives here in the Balena console:

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

novpaul, 2024-12-10:
Thanks all for the input-  will try the API key and see where that gets me Thursday/Friday

chrisys, 2024-12-13:
Just wanted to say thanks to everyone here for contributing and working to figure out what's going on!

@novpaul I would also share here the other values you've used in addition to the API key, maybe we can reproduce that way.

novpaul, 2024-12-23:
Hi all wanted to report back. I inputted the API key and no cigar unfortunately. I am now going to start from scratch again in the instructions and quadruple check pin out (I dont think this was incorrect) I have attached some screenshots if that helps from Balina Cloud... any further clues whilst working this out would be helpful as we crash into the Christmas period :-)
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

novpaul, 2024-12-23:
[train-departure-display_calm-feather-2024-12-23t17_38_26+00_00.txt](https://github.com/user-attachments/files/18231926/train-departure-display_calm-feather-2024-12-23t17_38_26%2B00_00.txt)

Adding the log if that is helpful as well

novpaul, 2024-12-23:
Update: So I have redone the pin layout and it's definitely correct. I'm at a bit of a loss now. API key is correct. I'm getting the log below. Is there any way I can test the display to ensure the part is working, or is there more work needed (based on the log) to exhaust all avenues before blaming/investigating the screen itself for defect? Thanks - P

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

jruys, 2024-12-23:
Log looks promising, I would expect a boot screen with IP address etc show
up as a minimum but no luck. Back to hardware checking.

Another potential suspect could be the 4SPI hardware display setting.
Double check the section under "configuring the display" at the link below?
I know from experience if that's done wrong display also stays dark.

https://github.com/chrisys/train-departure-display/blob/main/docs/02-connecting-the-display-to-the-pi.md

Alternatively, send us a picture of that part of your display?

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

novpaul, 2024-12-24:
@jruys thanks again for taking the time to comment. I've attached the picture. Is the resistor the thing with three spots positioned in R6? Would I use a soldering iron to heat up the solder and remove it completely and then put a solder blob between R5 and R6, joining them together?

Hopefully this is the fix :)

novpaul, 2024-12-24:
@jruys thanks again for taking the time to comment. I've attached the picture. Is the resistor the thing with three spots positioned in R6? Would I use a soldering iron to heat up the solder and remove it completely and then put a solder blob between R5 and R6, joining them together?

Hopefully this is the fix :)

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

jruys, 2024-12-24:
Yes - Getting close...

The R5 area should look like R8 - a solder blob or miniscule piece of wire between the two pins (or a 000 resistor but don't bother - same thing).
The R6 area should be clear, just like R7 looks now.

novpaul, 2024-12-24:
Amazing all sorted thanks so much, what a lovely Christmas gift!! Thanks for everyone's help - super stars

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

chrisys, 2025-08-08:
Thanks @jruys for helping out here - what a guy 🤩 Congrats on getting the project running @novpaul

Closed 2025-08-08.

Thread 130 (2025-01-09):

CAD models?

jimmykl, 2025-01-09:
Any chance that you could provide CAD model files for the case components?

I'm looking to tweak the desk mount with a channel/hole for the USB cable and some way to add some weight (possibly a magnet)

MrDeformat, 2025-01-09:
Hey Jimmy, you should be able to use the files provided in certain software, I used tinkercad to do some rudimentary changes to my case.

chrisys, 2025-01-18:
@jimmykl as mentioned above you should be able to do this with the STL files. Is there anything else I can provide that would make it easier? If you make improvements, it'd be great to get them integrated back into the main repo - especially the weight/magnets idea! Mine is always falling over as well.

chrisys, 2025-06-10:
Will close this for now as I believe the STL files should be suitable - if not please reopen and let me know!

Closed 2025-06-10.

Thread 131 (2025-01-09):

Can't get screen to work (using new 3.1" screen)

MrDeformat, 2025-01-09:
I successfully built the project last year with a 2.80" display (thanks Chris!) unfortunately it was above the kettle and it stopped working, so I ordered three sets of Raspberry Pi Zero and chose the slightly larger 3.12" displays now available.

- Have moved the 0ohm resister
- flashing with original code and I am getting a solid fps on Balena but blank screen
- have wired with simple push in wires

I'm out of ideas as to whats wrong is it my shonky wiring?

Tried flashing with a fresh install, but it gets stuck on: Creating network 'default'

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

chrisys, 2025-01-18:
Hey @MrDeformat - at a glance I'd say your solder connections need attention. Both the solder blob and the connections to the Pi look like they have the potential to be causing issues - I'm not saying that's definitely the case but you want to get the solder to 'flow' and fill the hole. It looks like the temperature on your iron was too low.

That being said I'm also unsure about these new displays - I'm assuming there are others that have had success with them, and I don't see why they wouldn't work if the controller is the same, but I don't have first hand experience.

91880, 2025-01-23:
Hi @MrDeformat !

Just came across the thread and I am in the same boat as you. I have exactly the same screen. I have doubled checked the pin spec and they are the same as @chrisys original guide. I have the jumpers correct to enable 4SPI. I've tripled checked my connections and they are all good with along with continuity on a meter.

I'm new to Balena and Raspberry Pi other than an internet radio project a few years ago, which is why I have a pi zero w which I am now using for this.

Not sure what the log on my screenshot means as you have green text.

No idea where to go next.

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

MrDeformat, 2025-01-27:
Hey @91880 looks like your board is stuck on supervisor starting, it's not loading up and sending any signal to the screen yet, I believe thats Balena's supervisor, the code that manages it, you may want to test previous supervisor versions, also double check your device configuration, and api key for any errors, you should be getting an updated fps rate in the logs, like my screenshot.

Let us know if you get it working, I'm certain its not the screen thats the issue, they are just plug and play and exactly the same layout as the last boards

91880, 2025-01-27:
Thanks for this @MrDeformat

Will have a play and see if I can get any further forward. Will update on progress when I can.

91880, 2025-01-30:
Well this is proving challenging. I've tried three different SD Cards. All decent spec and wokring fine. I've tried flashing the image with both Etcher and with USBImager. I can see it in Balena Cloud each time but no progress on Supervisor State.

MrDeformat, 2025-01-30:
Thats frustrating, have you tried rolling back and using an earlier version, of both Balena, and the Train Time display software,

91880, 2025-01-30:
I can see I can select earlier OS versions, not sure which one I should go for? In terms of earlier version of the train display software, I just use the deploy to balena button. I don't know how to do it another way but I can learn!

MrDeformat, 2025-01-30:
Logged into my Balena and I think Supervisor version:14.9.4

Is the one that works for me

I will sit down ain a few weeks a properly look at the issue

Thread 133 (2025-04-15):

3D Printing - 3.12" Display

bigalxyz, 2025-04-15:
Trying to build this project with a 3.12" SPI Display from AliExpress: https://www.aliexpress.com/item/1005007321062605.html?spm=a2g0o.order_list.order_list_main.5.22131802CIc7sS

I failed to spot that the 3D files are for a 2.8" display, and the display doesn't quite fit sadly.

Does anyone have suitable shapefiles for this bigger display please? Or should I try to get hold of one of the 2.8" displays instead?

Thank you.

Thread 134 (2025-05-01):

"AssertionError" / Stuck at

OnStandBi00, 2025-05-01:
Using Raspberry Pi Zero 2 W and a small HD screen (before doing the wiring).
Upon booting, the pi shows the boot image, but then doesn't do anything else.
On the logs, I see the following messages roughly every 30 seconds:
"
main  Starting Train Departure Display v0.5.5
main  Traceback (most recent call last):
  File "/usr/src/app/src/main.py", line 517, in <module>
    virtual.refresh()
  File "/usr/src/python-packages/luma/core/virtual.py", line 123, in refresh
   im = self._backing_image.crop(box=self._crop_box())
                                      ^^^^^^^^^^^^^^^^
  File "/usr/src/python-packages/luma/core/virtual.py", line 135, in _crop_box
    assert 0 <= top <= bottom <= self.height
           ^^^^^^^^^^^^^^^^^^^^^^^^^^^^^^^^^
AssertionError
Service exited 'main sha256:66d96cf4132b46a60c1c17e210f9d64ffc50a58879cd73fd459334d4a43a1c26'
Restarting service 'main sha256:66d96cf4132b46a60c1c17e210f9d64ffc50a58879cd73fd459334d4a43a1c26'
"
If there is any suggestions, I have tried reformatting the SD card, redeploying the fleet, fiddling with the variables and trying to deploy both as Personal and Development. Nothing has seemed to work.

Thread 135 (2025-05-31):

Fixed but for info - unable to connect to WIFI / Balena Cloud

TellinStories, 2025-05-31:
Just in case anyone else has the same problem, I couldn't get this to work - it just wouldn't show as a device in Balena Cloud.  I worked out that it wasn't connecting to my router.  Firstly I made sure my router was using 2.4Ghz as the Pi Zero can't connect to 5 Ghz, however it still didn't work.  I eventually found out that it is because my router SSID contains a special character - I was able to go into the files on the SD card and manually enter my SSID and this fixed it.

Anyway, working now and love it!  Thanks!

chrisys, 2025-06-05:
Hey @TellinStories thanks for highlighting this and glad you enjoyed the project. I'll incorporate a note into the docs when I get a minute.

chrisys, 2025-06-13:
@TellinStories can you confirm what the special character was so I can attempt to reproduce this please?

TellinStories, 2025-06-13:
It is “&”Sent from my iPhoneOn 13 Jun 2025, at 10:16, Chris Crocker-White ***@***.***> wrote: chrisys left a comment (chrisys/train-departure-display#135)
@TellinStories can you confirm what the special character was so I can attempt to reproduce this please?

—Reply to this email directly, view it on GitHub, or unsubscribe.You are receiving this because you were mentioned.Message ID: ***@***.***>

chrisys, 2025-06-13:
@TellinStories thanks - and did you edit the `balena-wifi-01` file in system-connections? What change did you make?

chrisys, 2025-06-20:
Thanks for the extra detail @TellinStories! I have tried to replicate this many times now but have been unable to which is really strange. I can't what could be different on my end, so I'll leave this open for now in case someone else encounters the same problem.

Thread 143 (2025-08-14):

import RPi.GPIO as GPIO -  ModuleNotFoundError: No module named 'RPi' Running on a Ras Pi Zero 2 W

NateDogg92, 2025-08-14:
Having issues starting the default config due to the attached error. see below the snip

2025-08-14T12:54:30+01:00  main  Starting Train Departure Display v0.6.0
2025-08-14T12:54:30+01:00  main  Traceback (most recent call last):
2025-08-14T12:54:30+01:00  main    File "/usr/src/app/src/main.py", line 502, in <module>
2025-08-14T12:54:30+01:00  main      serial = spi(port=0)
2025-08-14T12:54:30+01:00  main               ^^^^^^^^^^^
2025-08-14T12:54:30+01:00  main    File "/usr/local/lib/python3.12/site-packages/luma/core/interface/serial.py", line 302, in __init__
2025-08-14T12:54:30+01:00  main      bitbang.__init__(self, gpio, transfer_size, reset_hold_time, reset_release_time, DC=gpio_DC, RST=gpio_RST)
2025-08-14T12:54:30+01:00  main    File "/usr/local/lib/python3.12/site-packages/luma/core/interface/serial.py", line 185, in __init__
2025-08-14T12:54:30+01:00  main      self._gpio = gpio or self.__rpi_gpio__()
2025-08-14T12:54:30+01:00  main                           ^^^^^^^^^^^^^^^^^^^
2025-08-14T12:54:30+01:00  main    File "/usr/local/lib/python3.12/site-packages/luma/core/lib.py", line 23, in __rpi_gpio__
2025-08-14T12:54:30+01:00  main      import RPi.GPIO as GPIO
2025-08-14T12:54:30+01:00  main  ModuleNotFoundError: No module named 'RPi'
2025-08-14T12:54:31+01:00 Service exited 'main sha256:454cc09c4237510ed9d7eb02851b3cecde15ceb9440881490a1f45b73e4363fb'
2025-08-14T12:54:28+01:00 Restarting service 'main sha256:454cc09c4237510ed9d7eb02851b3cecde15ceb9440881490a1f45b73e4363fb'

Any ideas?

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

NateDogg92, 2025-08-15:
@chrisys - This was exactly it thank you! not sure why it wasn't pulling the latest as i had set it to "latest release" but repulled and all is working again. Thanks for your help

Closed 2025-08-15.

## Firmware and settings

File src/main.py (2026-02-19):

import os
import time

import requests

from datetime import datetime
from PIL import ImageFont, Image, ImageDraw

from trains import loadDeparturesForStation
from config import loadConfig
from open import isRun

import RPi.GPIO as GPIO

from luma.core.interface.serial import spi, noop
from luma.core.render import canvas
from luma.oled.device import ssd1322
from luma.core.virtual import viewport, snapshot
from luma.core.sprite_system import framerate_regulator

import socket, re, uuid

def makeFont(name, size):
    font_path = os.path.abspath(
        os.path.join(
            os.path.dirname(__file__),
            'fonts',
            name
        )
    )
    return ImageFont.truetype(font_path, size, layout_engine=ImageFont.Layout.BASIC)


def renderDestination(departure, font, pos):
    departureTime = departure["aimed_departure_time"]
    destinationName = departure["destination_name"]

    def drawText(draw, *_):
        if config["showDepartureNumbers"]:
            train = f"{pos}  {departureTime}  {destinationName}"
        else:
            train = f"{departureTime}  {destinationName}"
        _, _, bitmap = cachedBitmapText(train, font)
        draw.bitmap((0, 0), bitmap, fill="yellow")

    return drawText


def renderServiceStatus(departure):
    def drawText(draw, width, *_):
        train = ""

        if departure["expected_departure_time"] == "On time":
            train = "On time"
        elif departure["expected_departure_time"] == "Cancelled":
            train = "Cancelled"
        elif departure["expected_departure_time"] == "Delayed":
            train = "Delayed"
        else:
            if isinstance(departure["expected_departure_time"], str):
                train = 'Exp ' + departure["expected_departure_time"]

            if departure["aimed_departure_time"] == departure["expected_departure_time"]:
                train = "On time"

        w, _, bitmap = cachedBitmapText(train, font)
        draw.bitmap((width - w, 0), bitmap, fill="yellow")
    return drawText


def renderPlatform(departure):
    def drawText(draw, *_):
        if "platform" in departure:
            platform = "Plat " + departure["platform"]
            if departure["platform"].lower() == "bus":
                platform = "BUS"
            _, _, bitmap = cachedBitmapText(platform, font)
            draw.bitmap((0, 0), bitmap, fill="yellow")
    return drawText


def renderCallingAt(draw, *_):
    stations = "Calling at: "
    _, _, bitmap = cachedBitmapText(stations, font)
    draw.bitmap((0, 0), bitmap, fill="yellow")


bitmapRenderCache = {}


def cachedBitmapText(text, font):
    # cache the bitmap representation of the stations string
    nameTuple = font.getname()
    fontKey = ''
    for item in nameTuple:
        fontKey = fontKey + item
    key = text + fontKey
    if key in bitmapRenderCache:
        # found in cache; re-use it
        pre = bitmapRenderCache[key]
        bitmap = pre['bitmap']
        txt_width = pre['txt_width']
        txt_height = pre['txt_height']
    else:
        # not cached; create a new image containing the string as a monochrome bitmap
        _, _, txt_width, txt_height = font.getbbox(text)
        bitmap = Image.new('L', [txt_width, txt_height], color=0)
        pre_render_draw = ImageDraw.Draw(bitmap)
        pre_render_draw.text((0, 0), text=text, font=font, fill=255)
        # save to render cache
        bitmapRenderCache[key] = {'bitmap': bitmap, 'txt_width': txt_width, 'txt_height': txt_height}
    return txt_width, txt_height, bitmap


# Create a class to hold scroll state for each screen
class ScrollState:
    def __init__(self):
        self.pixelsLeft = 1
        self.pixelsUp = 0
        self.hasElevated = 0
        self.pauseCount = 0
        self.stationRenderCount = 0


# Dictionary to store scroll state for each screen
scrollStates = {}


def renderStations(stations, screen_id='default'):
    def drawText(draw, *_):
        # Get or create scroll state for this screen
        if screen_id not in scrollStates:
            scrollStates[screen_id] = ScrollState()
        
        state = scrollStates[screen_id]

        if len(stations) == state.stationRenderCount - 5:
            state.stationRenderCount = 0

        txt_width, txt_height, bitmap = cachedBitmapText(stations, font)

        if state.hasElevated:
            # slide the bitmap left until it's fully out of view
            draw.bitmap((state.pixelsLeft - 1, 0), bitmap, fill="yellow")
            if -state.pixelsLeft > txt_width and state.pauseCount < 8:
                state.pauseCount += 1
                state.pixelsLeft = 0
                state.hasElevated = 0
            else:
                state.pauseCount = 0
                state.pixelsLeft = state.pixelsLeft - 1
        else:
            # slide the bitmap up from the bottom of its viewport until it's fully in view
            draw.bitmap((0, txt_height - state.pixelsUp), bitmap, fill="yellow")
            if state.pixelsUp == txt_height:
                state.pauseCount += 1
                if state.pauseCount > 20:
                    state.hasElevated = 1
                    state.pixelsUp = 0
            else:
                state.pixelsUp = state.pixelsUp + 1

    return drawText


def renderTime(draw, width, *_):
    rawTime = datetime.now().time()
    hour, minute, second = str(rawTime).split('.')[0].split(':')

    w1, _, HMBitmap = cachedBitmapText("{}:{}".format(hour, minute), fontBoldLarge)
    w2, _, _ = cachedBitmapText(':00', fontBoldTall)
    _, _, SBitmap = cachedBitmapText(':{}'.format(second), fontBoldTall)

    draw.bitmap(((width - w1 - w2) / 2, 0), HMBitmap, fill="yellow")
    draw.bitmap((((width - w1 - w2) / 2) + w1, 5), SBitmap, fill="yellow")

def renderDebugScreen(lines):
    def drawDebug(draw, *_):
        # draw a box
        draw.rectangle((1, 1, 254, 45), outline="yellow", fill=None)

        # coords for each line of text
        coords = {
            '1A': (5, 5),
            '1B': (45, 5),
            '2A': (5, 18),
            '2B': (45, 18),
            '3A': (5, 31),
            '3B': (45, 31),
            '3C': (140, 31)
        }

        # loop through lines and check if cached
        for key, text in lines.items():
            w, _, bitmap = cachedBitmapText(text, font)
            draw.bitmap(coords[key], bitmap, fill="yellow")        

    return drawDebug

def renderWelcomeTo(xOffset):
    def drawText(draw, *_):
        text = "Welcome to"
        draw.text((int(xOffset), 0), text=text, font=fontBold, fill="yellow")

    return drawText


def renderPoweredBy(xOffset):
    def drawText(draw, *_):
        text = "Powered by"
        draw.text((int(xOffset), 0), text=text, font=fontBold, fill="yellow")

    return drawText


def renderNRE(xOffset):
    def drawText(draw, *_):
        text = "National Rail Enquiries"
        draw.text((int(xOffset), 0), text=text, font=fontBold, fill="yellow")

    return drawText


def renderName(xOffset):
    def drawText(draw, *_):
        text = "UK Train Departure Display"
        draw.text((int(xOffset), 0), text=text, font=fontBold, fill="yellow")

    return drawText

def renderVersion(xOffset):
    def drawText(draw, *_):
        text = "v" + getVersionNumber().strip() + " " + getVersionDate()
        draw.text((int(xOffset), 0), text=text, font=font, fill="yellow")

    return drawText

def renderDepartureStation(departureStation, xOffset):
    def draw(draw, *_):
        text = departureStation
        draw.text((int(xOffset), 0), text=text, font=fontBold, fill="yellow")

    return draw


def renderDots(draw, *_):
    text = ".  .  ."
    draw.text((0, 0), text=text, font=fontBold, fill="yellow")


def loadData(apiConfig, journeyConfig, config):
    runHours = []
    if config['hoursPattern'].match(apiConfig['operatingHours']):
        runHours = [int(x) for x in apiConfig['operatingHours'].split('-')]

    if len(runHours) == 2 and isRun(runHours[0], runHours[1]) is False:
        return False, False, journeyConfig['outOfHoursName']

    # set rows to 10 (max allowed) to get as many departure as poss
    # leaving as a variable so this can be updated if the API does
    rows = "10"

    try:
        departures, stationName = loadDeparturesForStation(
            journeyConfig, apiConfig["apiKey"], rows)

        if departures is None:
            return False, False, stationName

        firstDepartureDestinations = departures[0]["calling_at_list"]
        return departures, firstDepartureDestinations, stationName
    except requests.RequestException as err:
        print("Error: Failed to fetch data from OpenLDBWS")
        print(err.__context__)
        return False, False, journeyConfig['outOfHoursName']


def drawStartup(device, width, height):
    virtualViewport = viewport(device, width=width, height=height)

    with canvas(device):
        nameSize = int(fontBold.getlength("UK Train Departure Display"))
        versionSize = int(font.getlength("v" + getVersionNumber().strip() + " " + getVersionDate()))
        poweredSize = int(fontBold.getlength("Powered by"))
        NRESize = int(fontBold.getlength("National Rail Enquiries"))

        rowOne = snapshot(width, 10, renderName((width - nameSize) / 2), interval=10)
        rowTwo = snapshot(width, 10, renderVersion((width - versionSize) / 2), interval=10)
        rowThree = snapshot(width, 10, renderPoweredBy((width - poweredSize) / 2), interval=10)
        rowFour = snapshot(width, 10, renderNRE((width - NRESize) / 2), interval=10)

        if len(virtualViewport._hotspots) > 0:
            for hotspot, xy in virtualViewport._hotspots:
                virtualViewport.remove_hotspot(hotspot, xy)

        virtualViewport.add_hotspot(rowOne, (0, 0))
        virtualViewport.add_hotspot(rowTwo, (0, 12))
        virtualViewport.add_hotspot(rowThree, (0, 24))
        virtualViewport.add_hotspot(rowFour, (0, 36))

    return virtualViewport

def drawDebugScreen(device, width, height, screen="1", showTime=False):
    virtualViewport = viewport(device, width=width, height=height)

    versionNumber = getVersionNumber().strip()
    
    ipAddress = getIp()

    macAddress = ':'.join(re.findall('..', '%012x' % uuid.getnode())).upper()

    debugLines = {}

    # ok let's build the strings, there's a bit of optional data here so let's do it the old fashioned way with appends

    debugLines["1A"] = "Display"

    debugLines["1B"] = f"= {config['journey']['departureStation']}"

    # has a destination been set? add it in!
    if(config["journey"]["destinationStation"]):
        debugLines["1B"] += f"->{config['journey']['destinationStation']}"

    # what about a plaform?
    if(config["journey"]["screen"+screen+"Platform"]):
        debugLines["1B"] += f" (Plat{config['journey']['screen'+screen+'Platform']}) "
    else:
        debugLines["1B"] += " (PlatAll) "

    # refresh time
    debugLines["1B"] += f"{config['refreshTime']}s "
    
    # this wasn't set on my default so will wrap it in if, just in case
    if(config['api']['operatingHours']):
        debugLines["1B"] += f"{config['api']['operatingHours']}h"
    
    debugLines["2A"] = "Script"
    debugLines["2B"] = f"= T_D_D:  {versionNumber}"

    debugLines["3A"] = "Address"
    debugLines["3B"] = f"= {macAddress}"
    debugLines["3C"] = f"IP={ipAddress}"

    theBox = snapshot(width, 64, renderDebugScreen(debugLines), interval=config["refreshTime"])
    virtualViewport.add_hotspot(theBox, (0, 0))

    if(showTime):
        rowTime = snapshot(width, 14, renderTime, interval=0.1)
        virtualViewport.add_hotspot(rowTime, (0, 50))

    return virtualViewport




def drawBlankSignage(device, width, height, departureStation):
    welcomeSize = int(fontBold.getlength("Welcome to"))
    stationSize = int(fontBold.getlength(departureStation))

    device.clear()

    virtualViewport = viewport(device, width=width, height=height)

    rowOne = snapshot(width, 10, renderWelcomeTo(
        (width - welcomeSize) / 2), interval=config["refreshTime"])
    rowTwo = snapshot(width, 10, renderDepartureStation(
        departureStation, (width - stationSize) / 2), interval=config["refreshTime"])
    rowThree = snapshot(width, 10, renderDots, interval=config["refreshTime"])
    # this will skip a second sometimes if set to 1, but a hotspot burns CPU
    # so set to snapshot of 0.1; you won't notice
    rowTime = snapshot(width, 14, renderTime, interval=0.1)

    if len(virtualViewport._hotspots) > 0:
        for vhotspot, xy in virtualViewport._hotspots:
            virtualViewport.remove_hotspot(vhotspot, xy)

    virtualViewport.add_hotspot(rowOne, (0, 0))
    virtualViewport.add_hotspot(rowTwo, (0, 12))
    virtualViewport.add_hotspot(rowThree, (0, 24))
    virtualViewport.add_hotspot(rowTime, (0, 50))

    return virtualViewport


def platform_filter(departureData, platformNumber, station):
    platformDepartures = []
    for sub in departureData:
        if platformNumber == "":
            platformDepartures.append(sub)
        elif sub.get('platform') is not None:
            if sub['platform'] == platformNumber:
                res = sub
                platformDepartures.append(res)

    if len(platformDepartures) > 0:
        firstDepartureDestinations = platformDepartures[0]["calling_at_list"]
        platformData = platformDepartures, firstDepartureDestinations, station
    else:
        platformData = platformDepartures, "", station

    return platformData


def drawSignage(device, width, height, data, screen_id='default'):
    virtualViewport = viewport(device, width=width, height=height)

    status = "Exp 00:00"
    callingAt = "Calling at: "
    platform = "Plat 888"

    departures, firstDepartureDestinations, departureStation = data

    w = int(font.getlength(callingAt))

    callingWidth = w
    width = virtualViewport.width

    # First measure the text size
    w = int(font.getlength(status))
    pw = int(font.getlength(platform))

    if len(departures) == 0:
        noTrains = drawBlankSignage(device, width=width, height=height, departureStation=departureStation)
        return noTrains

    firstFont = font
    if config['firstDepartureBold']:
        firstFont = fontBold

    rowOneA = snapshot(
        width - w - pw - 5, 10, renderDestination(departures[0], firstFont, '1st'), interval=config["refreshTime"])
    rowOneB = snapshot(w, 10, renderServiceStatus(
        departures[0]), interval=10)
    rowOneC = snapshot(pw, 10, renderPlatform(departures[0]), interval=config["refreshTime"])
    rowTwoA = snapshot(callingWidth, 10, renderCallingAt, interval=config["refreshTime"])
    rowTwoB = snapshot(width - callingWidth, 10,
                       renderStations(firstDepartureDestinations, screen_id), interval=0.02)

    if len(departures) > 1:
        rowThreeA = snapshot(width - w - pw, 10, renderDestination(
            departures[1], font, '2nd'), interval=config["refreshTime"])
        rowThreeB = snapshot(w, 10, renderServiceStatus(
            departures[1]), interval=config["refreshTime"])
        rowThreeC = snapshot(pw, 10, renderPlatform(departures[1]), interval=config["refreshTime"])

    if len(departures) > 2:
        rowFourA = snapshot(width - w - pw, 10, renderDestination(
            departures[2], font, '3rd'), interval=10)
        rowFourB = snapshot(w, 10, renderServiceStatus(
            departures[2]), interval=10)
        rowFourC = snapshot(pw, 10, renderPlatform(departures[2]), interval=config["refreshTime"])

    rowTime = snapshot(width, 14, renderTime, interval=0.1)

    if len(virtualViewport._hotspots) > 0:
        for vhotspot, xy in virtualViewport._hotspots:
            virtualViewport.remove_hotspot(vhotspot, xy)

    virtualViewport.add_hotspot(rowOneA, (0, 0))
    virtualViewport.add_hotspot(rowOneB, (width - w, 0))
    virtualViewport.add_hotspot(rowOneC, (width - w - pw, 0))
    virtualViewport.add_hotspot(rowTwoA, (0, 12))
    virtualViewport.add_hotspot(rowTwoB, (callingWidth, 12))

    if len(departures) > 1:
        virtualViewport.add_hotspot(rowThreeA, (0, 24))
        virtualViewport.add_hotspot(rowThreeB, (width - w, 24))
        virtualViewport.add_hotspot(rowThreeC, (width - w - pw, 24))

    if len(departures) > 2:
        virtualViewport.add_hotspot(rowFourA, (0, 36))
        virtualViewport.add_hotspot(rowFourB, (width - w, 36))
        virtualViewport.add_hotspot(rowFourC, (width - w - pw, 36))

    virtualViewport.add_hotspot(rowTime, (0, 50))

    return virtualViewport

def getIp():
    s = socket.socket(socket.AF_INET, socket.SOCK_DGRAM)
    s.settimeout(0)
    try:
        # doesn't even have to be reachable
        s.connect(('10.254.254.254', 1))
        IP = s.getsockname()[0]
    except Exception:
        IP = '127.0.0.1'
    finally:
        s.close()
    return IP

def getVersionNumber():
    version_file = open('version.txt', 'r')
    return version_file.read()

def getVersionDate():
    modification_timestamp = os.path.getmtime('version.txt')

    # Convert the timestamp to a readable datetime object
    return datetime.fromtimestamp(modification_timestamp).strftime('%d %b %Y')

try:
    print('Starting Train Departure Display v' + getVersionNumber())
    config = loadConfig()
    if config['headless']:
        print('Headless mode, running main loop without serial comms')
        serial = noop()
    else:
        GPIO.setwarnings(False)
        serial = spi(port=0)
        
    device = ssd1322(serial, mode="1", rotate=config['screenRotation'])

    if config['dualScreen']:
        serial1 = spi(port=1, gpio_DC=5, gpio_RST=6)
        device1 = ssd1322(serial1, mode="1", rotate=config['screenRotation'])
    font = makeFont("Dot Matrix Regular.ttf", 10)
    fontBold = makeFont("Dot Matrix Bold.ttf", 10)
    fontBoldTall = makeFont("Dot Matrix Bold Tall.ttf", 10)
    fontBoldLarge = makeFont("Dot Matrix Bold.ttf", 20)

    widgetWidth = 256
    widgetHeight = 64

    loop_count = 0

    regulator = framerate_regulator(config['targetFPS'])

    if (config['debug'] > 1):
        # render screen and sleep for specified seconds
        virtual = drawDebugScreen(device, width=widgetWidth, height=widgetHeight)
        virtual.refresh()
        if config['dualScreen']:
            virtual = drawDebugScreen(device, width=widgetWidth, height=widgetHeight, screen="2")
            virtual.refresh()
        time.sleep(config['debug'])
    else:
        # display NRE attribution while data loads
        virtual = drawStartup(device, width=widgetWidth, height=widgetHeight)
        virtual.refresh()
        if config['dualScreen']:
            virtual = drawStartup(device1, width=widgetWidth, height=widgetHeight)
            virtual.refresh()
        if config['headless'] is not True:
            time.sleep(5)

    timeAtStart = time.time() - config["refreshTime"]
    timeNow = time.time()
    timeFPS = time.time()

    blankHours = []
    if config['hoursPattern'].match(config['screenBlankHours']):
        blankHours = [int(x) for x in config['screenBlankHours'].split('-')]

    while True:
        with regulator:
            if len(blankHours) == 2 and isRun(blankHours[0], blankHours[1]):
                device.clear()
                if config['dualScreen']:
                    device1.clear()
                time.sleep(10)
            else:
                if timeNow - timeFPS >= config['fpsTime']:
                    timeFPS = time.time()
                    print('Effective FPS: ' + str(round(regulator.effective_FPS(), 2)))
                if timeNow - timeAtStart >= config["refreshTime"]:
                    # check if debug mode is enabled 
                    if config["debug"] == True:
                        print(config["debug"])
                        virtual = drawDebugScreen(device, width=widgetWidth, height=widgetHeight, showTime=True)
                        if config['dualScreen']:
                            virtual1 = drawDebugScreen(device1, width=widgetWidth, height=widgetHeight, showTime=True, screen="2")
                    else:
                        data = loadData(config["api"], config["journey"], config)
                        if data[0] is False:
                            virtual = drawBlankSignage(
                                device, width=widgetWidth, height=widgetHeight, departureStation=data[2])
                            if config['dualScreen']:
                                virtual1 = drawBlankSignage(
                                    device1, width=widgetWidth, height=widgetHeight, departureStation=data[2])
                        else:
                            departureData = data[0]
                            nextStations = data[1]
                            station = data[2]
                            screenData = platform_filter(departureData, config["journey"]["screen1Platform"], station)
                            virtual = drawSignage(device, width=widgetWidth, height=widgetHeight, data=screenData, screen_id='screen1')

                            if config['dualScreen']:
                                screen1Data = platform_filter(departureData, config["journey"]["screen2Platform"], station)
                                virtual1 = drawSignage(device1, width=widgetWidth, height=widgetHeight, data=screen1Data, screen_id='screen2')

                    timeAtStart = time.time()

                timeNow = time.time()
                virtual.refresh()
                if config['dualScreen']:
                    virtual1.refresh()

except KeyboardInterrupt:
    pass
except ValueError as err:
    print(f"Error: {err}")
# except KeyError as err:
#     print(f"Error: Please ensure the {err} environment variable is set")

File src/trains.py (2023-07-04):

import requests
import re
import xmltodict


def removeBrackets(originalName):
    return re.split(r" \(", originalName)[0]


def isTime(value):
    matches = re.findall(r"\d{2}:\d{2}", value)
    return len(matches) > 0


def joinwithCommas(listIN):
    return ", ".join(listIN)[::-1].replace(",", "dna ", 1)[::-1]


def removeEmptyStrings(items):
    return filter(None, items)


def joinWith(items, joiner: str):
    filtered_list = removeEmptyStrings(items)
    return joiner.join(filtered_list)


def joinWithSpaces(*args):
    return joinWith(args, " ")


def prepareServiceMessage(operator):
    return joinWithSpaces("A" if operator not in ['Elizabeth Line', 'Avanti West Coast'] else "An", operator, "Service")


def prepareLocationName(location, show_departure_time):
    location_name = removeBrackets(location['lt7:locationName'])

    if not show_departure_time:
        return location_name
    else:
        scheduled_time = location["lt7:st"]
        try:
            expected_time = location["lt7:et"]
        except KeyError:
            # as per api docs, it's 'at' if there isn't an 'et':
            expected_time = location["lt7:at"]
        departure_time = expected_time if isTime(expected_time) else scheduled_time
        formatted_departure = joinWith(["(", departure_time, ")"], "")
        return joinWithSpaces(location_name, formatted_departure)


def prepareCarriagesMessage(carriages):
    if carriages == 0:
        return ""
    else:
        return joinWithSpaces("formed of", carriages, "coaches.")


def ArrivalOrder(ServicesIN):
    ServicesOUT = []
    for servicenum, eachService in enumerate(ServicesIN):
        STDHour = int(eachService['lt4:std'][0:2])
        STDMinute = int(eachService['lt4:std'][3:5])
        if (STDHour < 2):
            STDHour += 24  # this prevents a 12am departure displaying before a 11pm departure
        STDinMinutes = STDHour * 60 + STDMinute  # this service is at this many minutes past midnight
        ServicesOUT.append(eachService)
        ServicesOUT[servicenum]['sortOrder'] = STDinMinutes
    ServicesOUT = sorted(ServicesOUT, key=lambda k: k['sortOrder'])
    return ServicesOUT


def ProcessDepartures(journeyConfig, APIOut):
    show_individual_departure_time = journeyConfig["individualStationDepartureTime"]
    APIElements = xmltodict.parse(APIOut)
    Services = []

    # get departure station name
    departureStationName = APIElements['soap:Envelope']['soap:Body']['GetDepBoardWithDetailsResponse']['GetStationBoardResult']['lt4:locationName']

    # if there are only train services from this station
    if 'lt7:trainServices' in APIElements['soap:Envelope']['soap:Body']['GetDepBoardWithDetailsResponse']['GetStationBoardResult']:
        Services = APIElements['soap:Envelope']['soap:Body']['GetDepBoardWithDetailsResponse']['GetStationBoardResult']['lt7:trainServices']['lt7:service']
        if isinstance(Services, dict):  # if there's only one service, it comes out as a dict
            Services = [Services]       # but it needs to be a list with a single element

        # if there are train and bus services from this station
        if 'lt7:busServices' in APIElements['soap:Envelope']['soap:Body']['GetDepBoardWithDetailsResponse']['GetStationBoardResult']:
            BusServices = APIElements['soap:Envelope']['soap:Body']['GetDepBoardWithDetailsResponse']['GetStationBoardResult']['lt7:busServices']['lt7:service']
            if isinstance(BusServices, dict):
                BusServices = [BusServices]
            Services = ArrivalOrder(Services + BusServices)  # sort the bus and train services into one list in order of scheduled arrival time

    # if there are only bus services from this station
    elif 'lt7:busServices' in APIElements['soap:Envelope']['soap:Body']['GetDepBoardWithDetailsResponse']['GetStationBoardResult']:
        Services = APIElements['soap:Envelope']['soap:Body']['GetDepBoardWithDetailsResponse']['GetStationBoardResult']['lt7:busServices']['lt7:service']
        if isinstance(Services, dict):
            Services = [Services]

    # if there are no trains or buses
    else:
        Services = None
        return None, departureStationName

    # we create a new list of dicts to hold the services
    Departures = [{}] * len(Services)

    for servicenum, eachService in enumerate(Services):
        thisDeparture = {}  # create empty dict to populate

        # next we move elements of dict eachService to dict thisDeparture one by one

        # get platform, if available
        if 'lt4:platform' in eachService:
            thisDeparture["platform"] = (eachService['lt4:platform'])

        # get scheduled departure time
        thisDeparture["aimed_departure_time"] = eachService["lt4:std"]

        # get estimated departure time
        thisDeparture["expected_departure_time"] = eachService["lt4:etd"]

        # get carriages, if available
        if 'lt4:length' in eachService:
            thisDeparture["carriages"] = eachService["lt4:length"]
        else:
            thisDeparture["carriages"] = 0

        # get operator, if available
        if 'lt4:operator' in eachService:
            thisDeparture["operator"] = eachService["lt4:operator"]

        # get name of destination
        if not isinstance(eachService['lt5:destination']['lt4:location'], list):    # the service only has one destination
            thisDeparture["destination_name"] = removeBrackets(eachService['lt5:destination']['lt4:location']['lt4:locationName'])
        else:  # the service splits and has multiple destinations
            DestinationList = [i['lt4:locationName'] for i in eachService['lt5:destination']['lt4:location']]
            thisDeparture["destination_name"] = " & ".join([removeBrackets(i) for i in DestinationList])

        # get via and add to destination name
        # if 'lt4:via' in eachService['lt5:destination']['lt4:location']:
        #    thisDeparture["destination_name"] += " " + eachService['lt5:destination']['lt4:location']['lt4:via']
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

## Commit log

2019-06-02 fix: Tweaks having tested on a real device
    [main.py, trains.py]
2019-06-02 Correctly refresh data and re-render the UI
    [main.py, trains.py]
2019-06-02 Resolve issues with rebase
    [main.py]
2019-06-02 Attempt to fix rendering logic by simplifying the loop
    [main.py]
2019-06-02 Adds two useful assets for wiring the hardware
2019-06-06 fix: Update config.sample.json structure
2019-06-06 fix: Respect configured refresh time
    [main.py]
2019-06-06 fix: Correct asset for the OLED SPI pin configuration image
2019-06-08 fix: Issue which prevented the program from refreshing
    [main.py]
2019-06-08 fix: Render correctly when only one service is available
    [main.py]
2019-07-05 Updated returned station names to shorten then for small displays, changed London to LDN, International to Intl.
    [trains.py]
2019-07-05 removed LDN shorten and fixed destination and orgin text swap
    [trains.py]
2019-07-06 abbreviation and operating hours added to config sample
2019-07-12 Change layout to prevent font stretching and add line
    Change-type: patch
    [main.py]
2019-07-23 Tidying plus bug fixes to handle empty values from the API
    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
    [main.py]
2019-07-26 Reduce image size further and reduce framerate to improve performance on Pi Zero
    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
2019-08-19 Added 3D case STL files
    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
    [case-back.stl, case-main.stl]
2019-08-20 Added connection diagram
    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
    [pi-display-connections.fzz]
2019-09-11 Add files via upload
    Added support for cancelled trains and bus replacement services
    [main.py]
2020-02-13 Remove piwheels - not currently building
    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
2020-05-26 Unlock framerate
    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
2020-09-08 Add DWB button for easier deployment
    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
2020-09-08 Add balena.yml with device and env var presets
    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
2021-07-07 Report API server errors fixes #29, fixes #32
    Resolve the case where if an API key/App ID is not specified it causes the code to report that the 'departures' variable is not set. This really means that it could not find the departure data in the API response because it was 500 erroring.
    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
    [trains.py]
2021-07-07 Reworked messy configuration setup
    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
    [config.py, main.py, trains.py]
2021-07-07 Added ability to filter by platform closes #7
    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
2021-07-09 Fix outOfHoursName config
    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
    [config.py]
2021-07-12 Add logging, adjust framerate
    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
2021-10-30 Change to National Rail Enquiries API
    Fixes #39
    Change-type: minor
    [config.py, main.py, trains.py]
2021-12-08 Update timeOffset key
    The timeOffset os.getenv was using the ScreenRefresh key. This commit
    updates it to use the correct key.
    [config.py]
2021-12-10 Set Dockerfile to use raspberry-pi base image
    Fixes #55 until we can build for aarch64
    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
2021-12-24 Add option for multi screen support
    Previously there was only support for a single screen. As I live at a
    two platform station and the Pi supports a pair of SPI busses it makes
    sense to enable the possibility of running a pair of screens,
    [pi-display-connections.fzz]
2022-01-17 Add modular case design
    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
    [back-cover.stl, case-body.stl, desk-mount.stl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]
2022-03-09 Adjust tolerances between case parts
    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
    [desk-mount.stl, hanging-mount.stl]
2022-05-17 Default to all-day operation fixes #72
    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
    [config.py, main.py, trains.py]
2022-05-30 Correct angle on desk mount lugs
    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
    [desk-mount.stl]
2022-05-31 Add assembly guide
    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
    [case-back.stl, case-main.stl]
2023-01-20 Correct crash when destinationStation set to null
    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
    [trains.py]
2023-01-26 Correctly handle when platform numbers set to null
    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
    [config.py, trains.py]
2023-02-12 Fix: Catches request errors to draw blank signage
    [main.py]
2023-02-12 Removes print
2023-02-18 Correct some boolean config vars defaulting to true
    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
    [config.py, main.py]
2023-06-29 Performance branch (#1)
    # Performance Branch
    The most computationally expensive thing to do on any computer is render a font. It's what Babbage fought with for years.
    I profiled the main loop of this code by vendoring in Luma, removing the threadpool, and running cProfile over it. That revealed two things:
    * Running the seconds as "hotspot" was burning up the CPU
    * The rest of the CPU time was spent "scrolling" the "calling at stations" as it required a full re-render of the string each time a character was dropped off the front of the string.
    * We've changed the scrolling behaviour to scroll the bitmap at 1 pixel per frame, rather than 1 character per frame. Smooth!
    * There's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
    [config.py, main.py, trains.py]
2023-07-21 Initial work on debug screen. Currently overrides main display; will fix when ready for PR
    [main.py]
2023-07-25 Added function to parse platform data and filter incorrect data
2024-02-27 Fixed regex for platforms above 10
    [config.py]
2025-06-10 Migrate away from base images and fixes
    Fixes #138 #123 #106 #75 #94
    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
    [config.py, main.py]
2025-07-06 Documentation fixes, suppressed warning - documentation updates - suppressed "GPIO In Use" error - https://github.com/chrisys/train-departure-display/issues/111
    [main.py]
2026-02-19 fix(dualscreen): Independent scrolling of 'calling at'
    Having global variables for pixelsLeft, pixelsUp, hasElevated, and pauseCount that were shared between screens caused the shortest calling at to trim the display of a longer calling at. This meant that useful information could be missed by the viewer as a fast train would impact the information being available on a stopping service departing from another platform.
    The variables have now been made instance specific in order to address this.
    [main.py]
